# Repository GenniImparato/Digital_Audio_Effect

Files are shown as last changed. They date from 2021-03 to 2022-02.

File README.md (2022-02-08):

 




# Digital_Audio_Effect

## Index

* ### [Overview](#intro)
* ### [Videos](#videos)
* ### [Requirements](#req)
  * #### [Hardware](#hw)
  * #### [Software](#sw)
* ### [Getting Started](#get)
* ### [DSP Effects](#dsp)
  * #### [Delay](#delay)
  * #### [Filter](#filter) 
* ### [Future Improvements](#future)

## Overview
This project is a platform to experiment with **real-time DSP effects** on
audio, with an STM32 microprocessor, using a multi-threaded, real-time environment.
The application has been developed on top of the **Miosix** embedded operative system which provided real-time operating system (RTOS) features, as well as a native multi-threaded enviroment.
A full detailed document explaining the project in details can be found at:
https://github.com/GenniImparato/Digital_Audio_Effect/blob/main/docs/report/Digital_Audio_Effects.pdf

## Videos
https://user-images.githubusercontent.com/37338634/153053574-94ea6515-ac46-4c21-b3ac-aa7877b238f6.mp4

https://user-images.githubusercontent.com/37338634/153054718-db798998-3f35-4ed6-b5b4-32b3baa28a30.mp4

https://user-images.githubusercontent.com/37338634/153054537-bed419cf-c9f3-40c2-ad0e-0b04481bedc5.mp4

## Requirements

### Hardware Requirements
- STM32F407 Discovery Board
- Custom PCB (see `hardware` folder for more details)

### Software Requirements
- [Miosix](https://miosix.org/) OS
- [QSTLink2](https://github.com/fpoussin/QStlink2) for board configuration

## Getting started

1. Connect the microcontroller to the PC with the USB cable or with the external power supply of the PCB.

2. Open `QSTLink2` to connect the board through the `connect` command.

3. Open a terminal, go to the `firmware` folder and type `make` to compile the project.

   ```
   cd path/to/project/firmware   
   make
   ```

4. From `QSTLink2`, send the code to the board through the `send` command.

## DSP Effects
The following are the implemented DSP effects, which values can be dinamically modified. 

### Delay
As the name implies, this effect delays the flow of the audio source by a given amount.

### Filter
This effect can be configured as:
- Low-pass filter
- High-pass filter
- Band-pass filter

Each of those modes can be dinamically changed, as well as their values.

## Future Improvements
**[+]** Implementation of more audio effects

**[+]** Anti-aliasing filtering

**[+]** Sine curves visualization

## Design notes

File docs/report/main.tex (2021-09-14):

%%%%%%%%%%%%%%%%%%%%%%%%%%%%%%%%%%%%%%%%%
% University Assignment Title Page 
% LaTeX Template
% Version 1.0 (27/12/12)
%
% This template has been downloaded from:
% http://www.LaTeXTemplates.com
%
% Original author:
% WikiBooks (http://en.wikibooks.org/wiki/LaTeX/Title_Creation)
%
% License:
% CC BY-NC-SA 3.0 (http://creativecommons.org/licenses/by-nc-sa/3.0/)
% 
% Instructions for using this template:
% This title page is capable of being compiled as is. This is not useful for 
% including it in another document. To do this, you have two options: 
%
% 1) Copy/paste everything between \begin{document} and \end{document} 
% starting at \begin{titlepage} and paste this into another LaTeX file where you 
% want your title page.
% OR
% 2) Remove everything outside the \begin{titlepage} and \end{titlepage} and 
% move this file to the same directory as the LaTeX file you wish to add it to. 
% Then add \input{./title_page_1.tex} to your LaTeX file where you want your
% title page.
%
%%%%%%%%%%%%%%%%%%%%%%%%%%%%%%%%%%%%%%%%%
%\title{Title page with logo}
%----------------------------------------------------------------------------------------
%	PACKAGES AND OTHER DOCUMENT CONFIGURATIONS
%----------------------------------------------------------------------------------------

\documentclass[12pt]{article}
\usepackage[english]{babel}
\usepackage[utf8x]{inputenc}
\usepackage{amsmath}
\usepackage{graphicx}
\usepackage{float}
\usepackage{listings}
\usepackage[colorinlistoftodos]{todonotes}
\usepackage{textcomp}

\usepackage{geometry}
 \geometry{
 a4paper,
 total={170mm,257mm},
 left=20mm,
 top=20mm,
 }
 
 % Better inline directory listings
\usepackage{xcolor}
\definecolor{light-gray}{gray}{0.95}
\newcommand{\code}[1]{\colorbox{light-gray}{\texttt{#1}}}

% Paragraph formatting
\setlength{\parindent}{0em}
\setlength{\parskip}{1em}

% Subsubsubsection
% \usepackage{titlesec}
% \setcounter{secnumdepth}{4}
% \titleformat{\paragraph}
% {\normalfont\normalsize\bfseries}{\theparagraph}{1em}{}
% \titlespacing*{\paragraph}
% {0pt}{3.25ex plus 1ex minus .2ex}{1.5ex plus .2ex}

\usepackage{titlesec}
\usepackage{hyperref}

\titleclass{\subsubsubsection}{straight}[\subsection]

\newcounter{subsubsubsection}[subsubsection]
\renewcommand\thesubsubsubsection{\thesubsubsection.\arabic{subsubsubsection}}
\renewcommand\theparagraph{\thesubsubsubsection.\arabic{paragraph}} % optional; useful if paragraphs are to be numbered

\titleformat{\subsubsubsection}
  {\normalfont\normalsize\bfseries}{\thesubsubsubsection}{1em}{}
\titlespacing*{\subsubsubsection}
{0pt}{3.25ex plus 1ex minus .2ex}{1.5ex plus .2ex}

\makeatletter
\renewcommand\paragraph{\@startsection{paragraph}{5}{\z@}%
  {3.25ex \@plus1ex \@minus.2ex}%
  {-1em}%
  {\normalfont\normalsize\bfseries}}
\renewcommand\subparagraph{\@startsection{subparagraph}{6}{\parindent}%
  {3.25ex \@plus1ex \@minus .2ex}%
  {-1em}%
  {\normalfont\normalsize\bfseries}}
\def\toclevel@subsubsubsection{4}
\def\toclevel@paragraph{5}
\def\toclevel@paragraph{6}
\def\l@subsubsubsection{\@dottedtocline{4}{7em}{4em}}
\def\l@paragraph{\@dottedtocline{5}{10em}{5em}}
\def\l@subparagraph{\@dottedtocline{6}{14em}{6em}}

% Format of references to sections
\AtBeginDocument{%
  \@ifdefinable{\myorg@nameref}{%
    \LetLtxMacro\myorg@nameref\nameref
    \DeclareRobustCommand*{\nameref}[1]{%
      \emph{\myorg@nameref{#1}}%
    }%
  }%
}

\makeatother

\setcounter{secnumdepth}{4}
\setcounter{tocdepth}{4}

\begin{document}
\textwidth=15cm

\lstset{language=C++,
                basicstyle=\fontsize{10}{10}\ttfamily,
                keywordstyle=\color{blue}\ttfamily,
                stringstyle=\color{red}\ttfamily,
                commentstyle=\color{gray!80}\ttfamily,
                morecomment=[l][\color{magenta}]{\#}
}

\begin{titlepage}

\newcommand{\HRule}{\rule{\linewidth}{0.5mm}} % Defines a new command for the horizontal lines, change thickness here

\center % Center everything on the page
 
%----------------------------------------------------------------------------------------
%	HEADING SECTIONS
%----------------------------------------------------------------------------------------

\textsc{\LARGE Politenico di Milano}\\[1.5cm] % Name of your university/college
\textsc{\Large Dipartimento Elettronica, Informazione e Bioingegneria}\\[0.5cm] % Major heading such as course name
\textsc{\large HEAPLab Project Report}\\[0.5cm] % Minor heading such as course title

%----------------------------------------------------------------------------------------
%	TITLE SECTION
%----------------------------------------------------------------------------------------

\HRule \\[0.4cm]
{ \huge \bfseries Digital Audio Effects}\\[0.4cm] % Title of your document
\HRule \\[1.5cm]
 
%----------------------------------------------------------------------------------------
%	AUTHOR SECTION
%----------------------------------------------------------------------------------------

\begin{minipage}{0.4\textwidth}
\begin{flushleft} \large
\emph{Authors:}\\
Generoso \textsc{Imparato} \newline
Yazan \textsc{Matar}
\end{flushleft}
\end{minipage}
~
\begin{minipage}{0.4\textwidth}
\begin{flushright} \large
\emph{Supervisor:} \\
Federico \textsc{Terraneo} % Supervisor's Name
\end{flushright}
\end{minipage}\\[2cm]

% If you don't want a supervisor, uncomment the two lines below and remove the section above
%\Large \emph{Author:}\\
%John \textsc{Smith}\\[3cm] % Your name

%----------------------------------------------------------------------------------------
%	DATE SECTION
%----------------------------------------------------------------------------------------

{\large \today}\\[2cm] % Date, change the \today to a set date if you want to be precise

%----------------------------------------------------------------------------------------
%	LOGO SECTION
%----------------------------------------------------------------------------------------

\\[1cm] % Include a department/university logo - this will require the graphicx package

\emph{Github repo:}\\
\href{https://github.com/GenniImparato/Digital\_Audio\_Effect}{https://github.com/GenniImparato/Digital\_Audio\_Effect}\par
 
%----------------------------------------------------------------------------------------

\vfill % Fill the rest of the page with whitespace

\end{titlepage}

\tableofcontents
\newpage

\section{Introduction}
\label{sec:Intro}

The aim of this project is to create a platform to experiment with real-time DSP effects on audio, with an STM32 microprocessor, using a multi-threaded, real-time environment. \\
We designed an audio chain system with the following specifications:

\begin{itemize}
    \item Input audio can be selected from two sources:
        \begin{itemize}
          \item Audio sampled from an analog audio signal coming from a jack connector
          \item Audio generated by a software audio synthesizer
        \end{itemize}
    \item Audio stream coming from the selected source can be sent through different selectable DSP effects 
    \item Output audio can be heard in real-time with a speaker, as well as earphones through the jack connector
    \item Synthesizer, as well as the effects, has parameters that can be changed in real-time.
\end{itemize}

To realize such functionalities, and to better visualize, hear, and control the system, we designed an auxiliary PCB with extra hardware which will be described in detail in the relative section.

\newpage

\section{Design and Implementation}
\label{sec:Design}
In this section we describe the hardware components and functionalities as well as the software implementation and how those components interact with one another.

\subsection{Hardware}
\label{sec:HW}
In the following sections we analyze in detail the hardware components used for this project, which are the \textbf{STM32F407 Discovery Board} and the \textbf{custom PCB} designed to improve the user experience.

\subsubsection{STM32F407 Discovery Board}
The microcontroller used for the project is the
STM32F407 Discovery Board, which offers (mainly for this project) the following features:

\begin{itemize}
    \item STM32F407VGT6 microcontroller featuring 32-bit Arm\textsuperscript{\textregistered} Cortex\textsuperscript{\textregistered}-M4 with FPU core
    \item 1-Mbyte Flash memory and 192-Kbyte RAM
    \item Audio DAC with integrated class D speaker driver
    \item User and reset push-buttons
    \item Stereo headphone output jack
    \item External application power supply: 3V and 5V
\end{itemize}
For more specifications about the board, read the datasheet and the user manual or go to the manufacturer website.

\subsubsection{Custom PCB}
\label{sec:PCB}
We designed a PCB in Eagle with connectors to insert the STM32F407 discovery board.
The PCB contains extra hardware useful for the project, such as:
\begin{itemize}
    \item Speaker with an amplifier circuit
    \item Audio buffer for ADC sampling
    \item Led matrix [10x15]
    \item Linear potentiometers (for effect controls)
    \item Logarithmic potentiometer (for amplifier volume)
    \item External power supply
\end{itemize}

Details on the PCB are shown in the next sections.

\subsubsubsection{Circuits}
\label{sec:Circuit}

    \begin{figure}[H]
      \centering
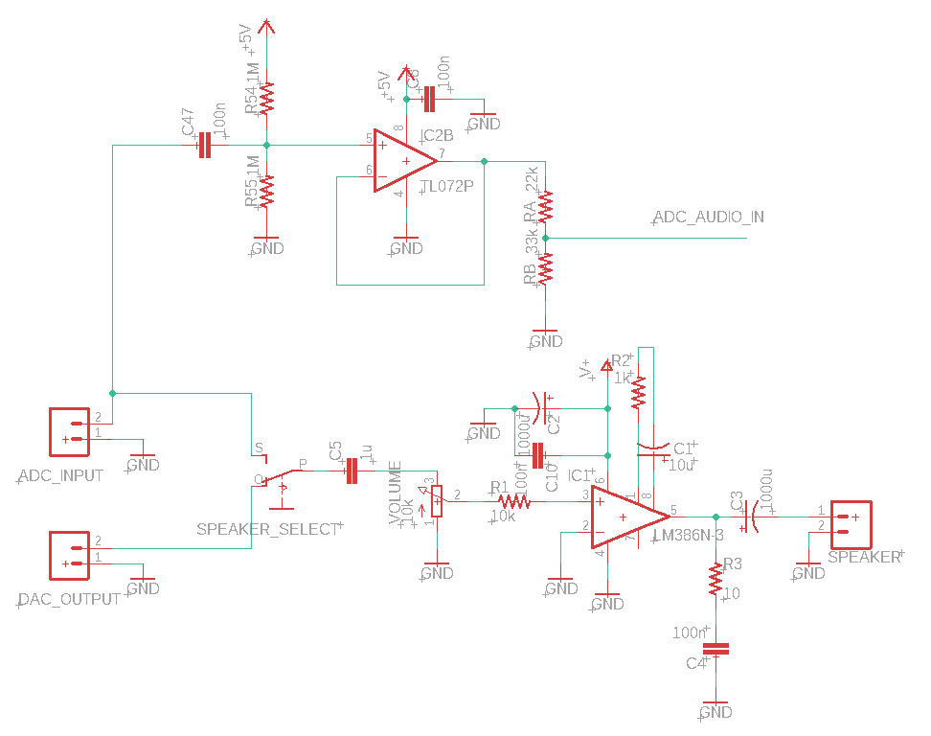
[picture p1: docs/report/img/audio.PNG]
        
        \caption{Audio circuit}
    \end{figure}
    
    This circuit contains a buffer between the input analog audio signal and the STM32 internal ADC input.\\
    The signal is shifted in range from 0 to 3.3V and centered around 1.65 V to be sampled by the ADC.\\
    It also contains the amplifier circuit that drives the 8 ohm speaker on the board, including a volume potentiometer. \\
    The input of the speaker amplifier can be selected with a switch between the raw input audio and the DAC output of the discovery board.
    
    \begin{figure}[H]
      \centering
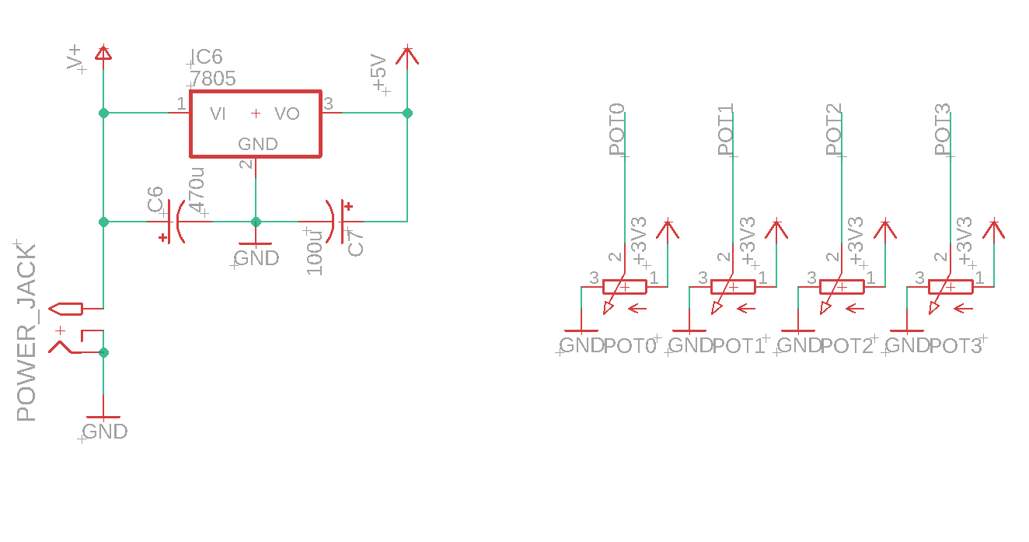
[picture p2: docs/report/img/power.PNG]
        
        \caption{Power and potentiometers circuit}
    \end{figure}
    
    The input voltage from the power is applied directly to the speaker amplifier power supply, while the voltage for the discovery board is obtained by a 5V voltage regulator.
    
    \begin{figure}[H]
      \centering
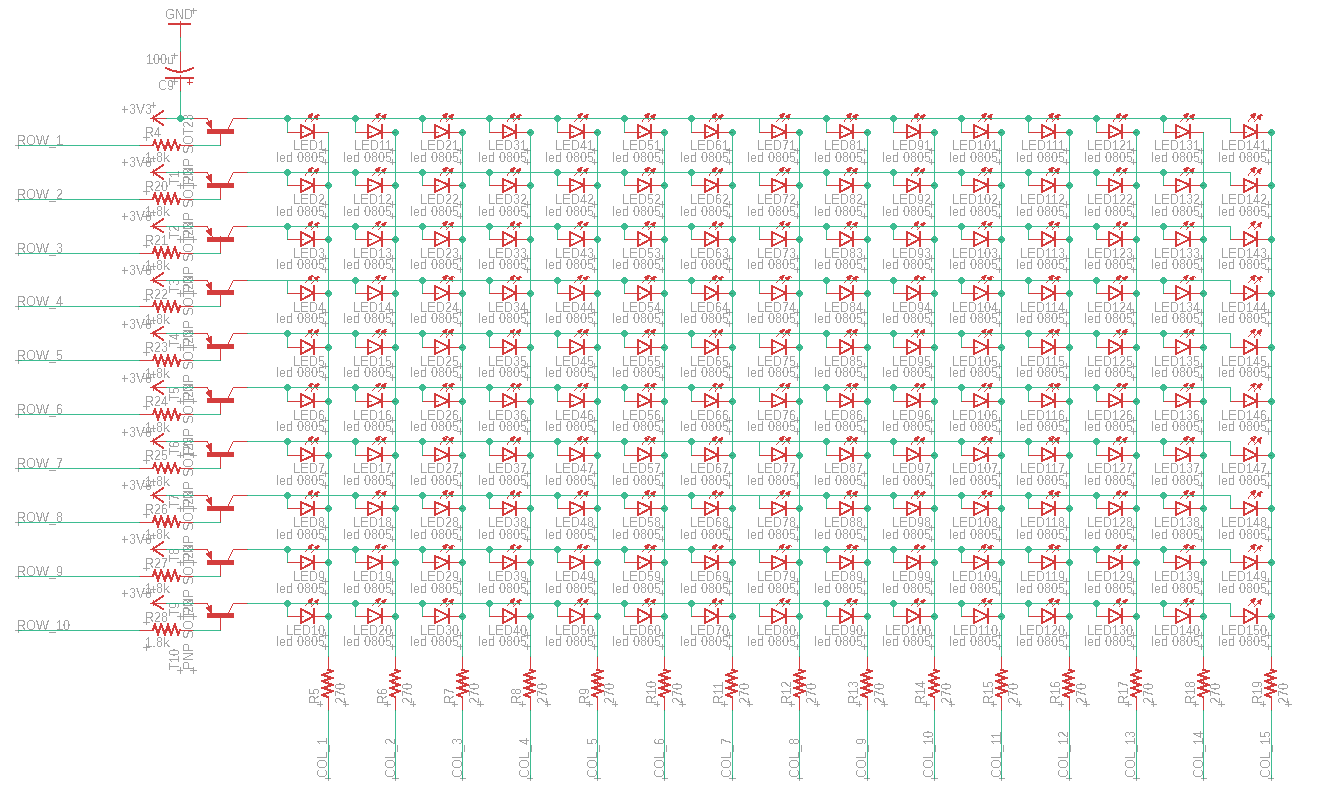
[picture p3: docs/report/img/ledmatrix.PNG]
        
        \caption{Led matrix circuit}
    \end{figure}
    
    The led matrix is made with 150 SMD leds, divided in 10 rows and 15 columns.\\
    Each row is controlled by a PNP transistor with the base connected to a GPIO pin of the discovery board. Columns are connected directly to GPIO pins.
    
    \begin{figure}[H]
      \centering
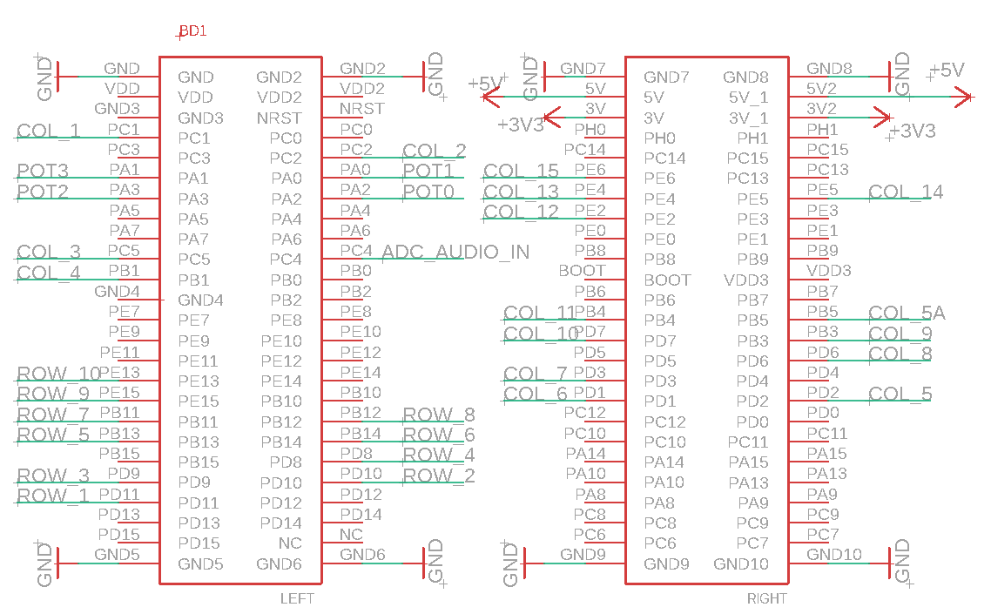
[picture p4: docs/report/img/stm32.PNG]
        
        \caption{STM32F407 Discovery Board connectors}
    \end{figure}
    
    This connectors allow to easily insert and remove the STM32F407 Discovery Board from the PCB.

\newpage
\subsubsubsection{Layout}
\label{sec:Layout}
    
    \begin{figure}[H]
      \centering
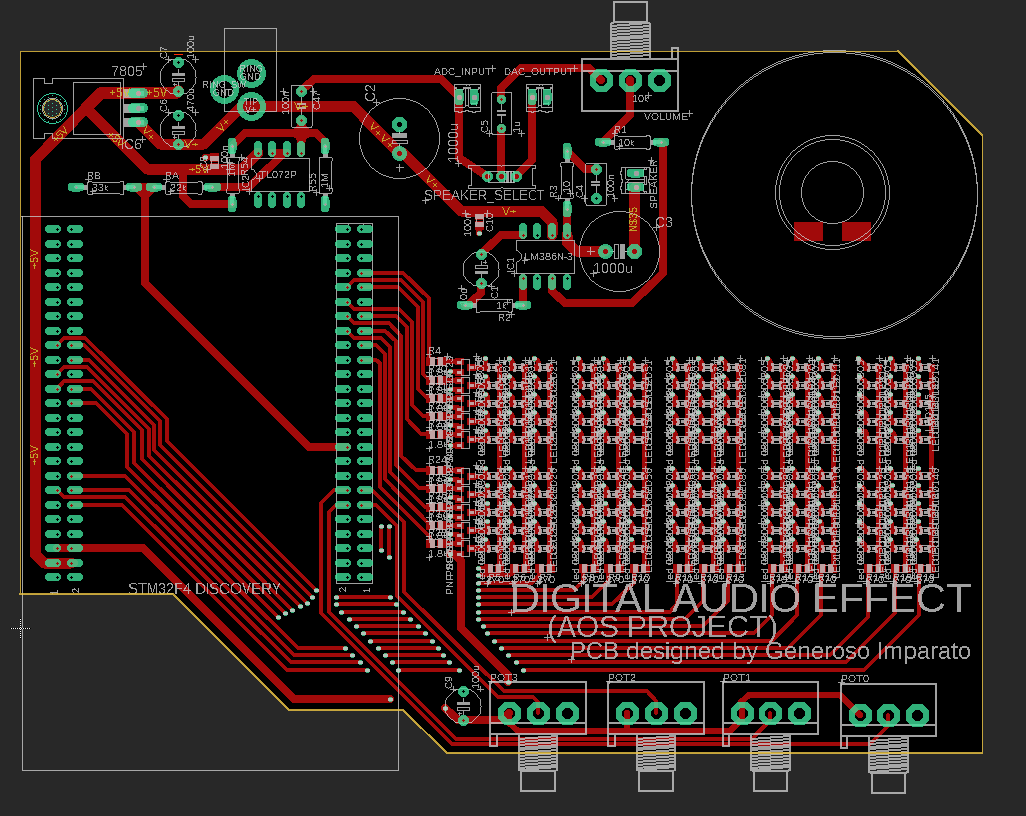
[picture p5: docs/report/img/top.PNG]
        
        \caption{top layer}
    \end{figure}
    
    \begin{figure}[H]
      \centering
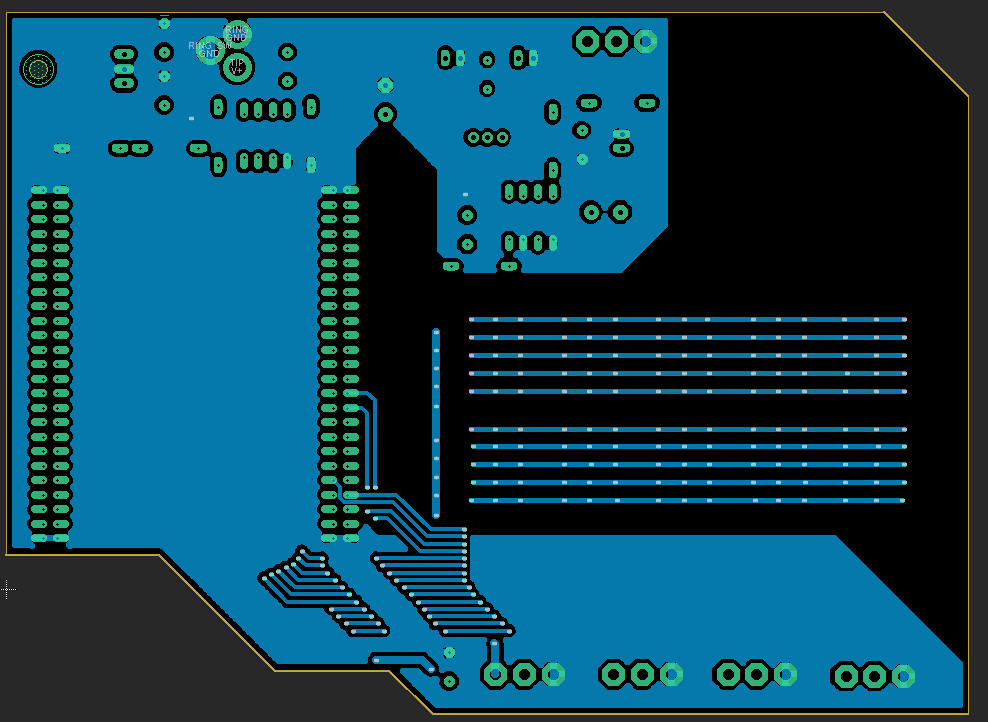
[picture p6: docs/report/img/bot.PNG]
        
        \caption{bottom layer}
    \end{figure}
    
    \newpage
    
    \subsubsubsection{Renderings}
    
    \begin{figure}[H]
      \centering
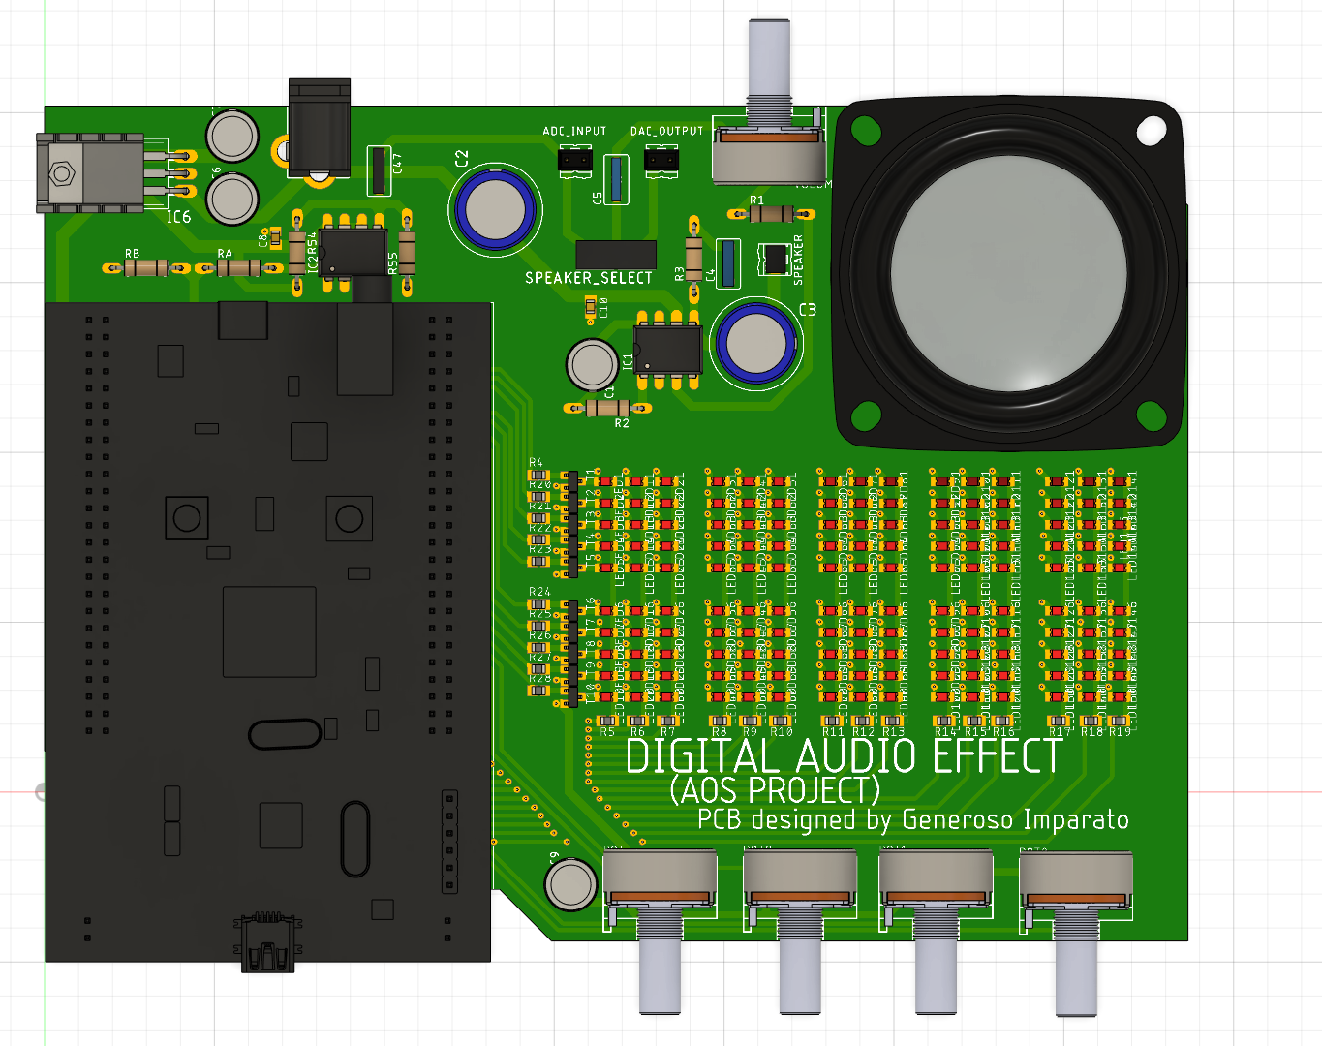
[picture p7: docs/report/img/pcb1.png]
        
    \end{figure}
    
    \begin{figure}[H]
      \centering
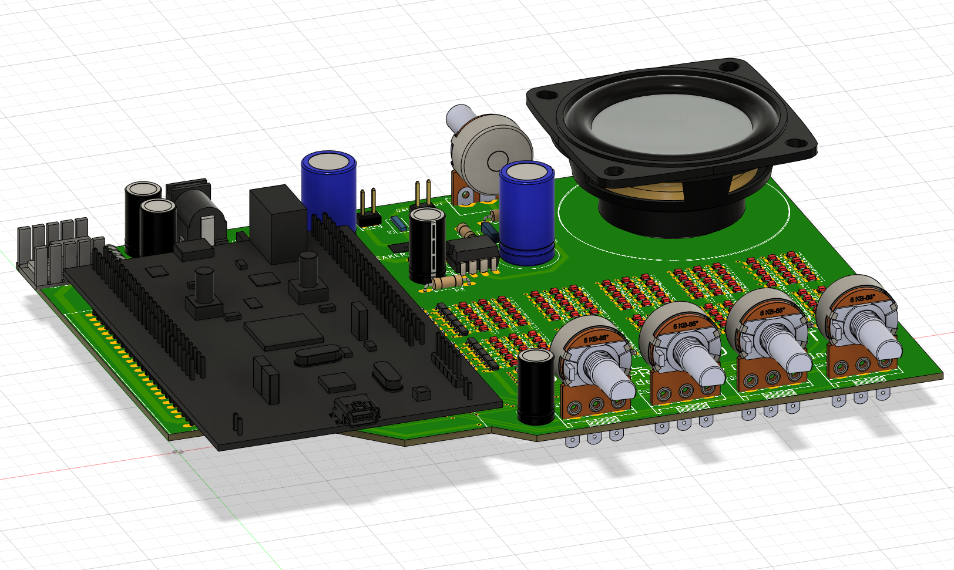
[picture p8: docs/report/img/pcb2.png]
        
    \end{figure}
    
    \vfill

\subsection{Software}
\label{sec:SW}
In this section we describe the real-time OS utilized, the structure of our code in terms of optimizations and scalability, as well as our design choices regarding the management of the various threads and the implementation of different drivers.\\
Finally, we talk about the digital audio effects and their implementation in detail.
    
\subsubsection{Miosix}
\label{sec:Miosix}

Miosix is an embedded OS kernel developed by Federico Terraneo designed to run on 32bit microcontrollers, especially on STM32, EFM32 and LPC2000 microcontroller families. \par

It is used for real-time operating applications and provides operative system abstraction layers such as single process, multi-threading and multi-process (experimental). \par

There is also support for the standard POSIX thread API (threads, mutexes and condition variables) other than full support for C and C++ standard libraries. The Miosix kernel is licensed under the GPL license.

\subsubsubsection{OS Choice}

This project heavily relies on multi-threading and real-time management, so this OS was a good fit, since it supports multi-threading natively, as well as synchronization mechanisms.\par

Another advantage is the small code size, fundamental for limited flash memory as in the case of most microcontrollers.

\subsubsection{Multi-threading Design}
\label{sec:Thread}

\begin{figure}[H]
    \begin{figure}[H]
    \centering
        
        \caption{Diagram Legenda}
    \end{figure}
        
    \centering
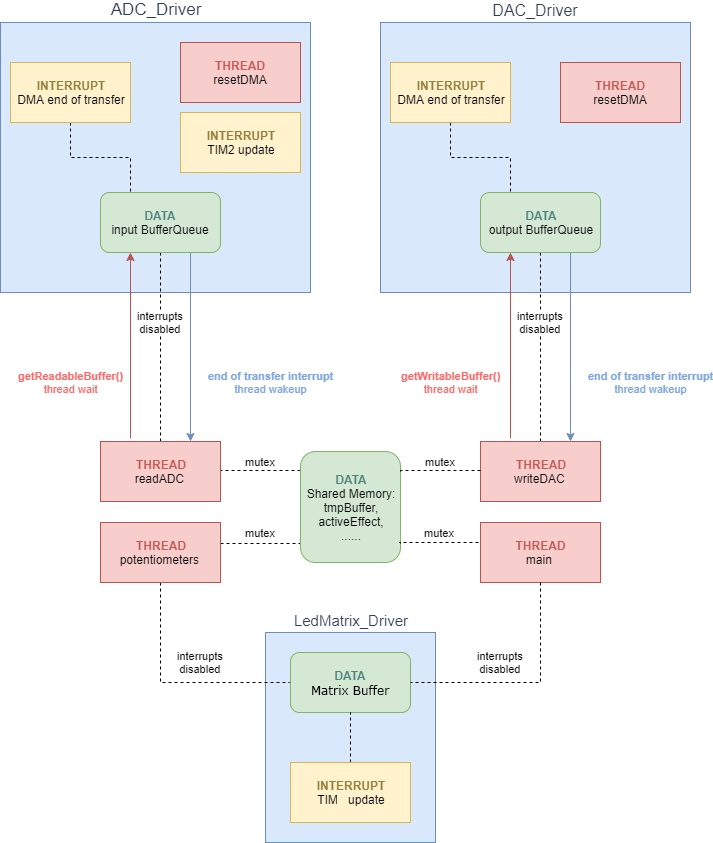
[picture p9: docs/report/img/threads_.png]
        
        \caption{Threads, interrupts and data access relationships}
\end{figure}
        
\newpage

The application is realized with 6 threads.
The two most important threads \code{readADC} and \code{writeDAC} have the highest priority because they should be responsive to allow the audio stream without lags or skipping buffers.\par
\code{readADC} reads from a buffer queue in the \code{ADC\_Driver}, which is filled with audio sampled from ADC at 44,1 kHZ, in a similar way \code{writeDAC} writes in the buffer queue of the \code{DAC\_Driver}.\\
When \code{getReadableBuffer()} is called the \code{readADC} thread is put in a wait state until a buffer is available to be read, when the DMA has finished the transfer.\\
In a similar way, when \code{getWritableBuffer()} is called, the \code{writeDAC} thread is put in wait until a buffer is available to be wrote. \par

In order for the threads to be synchronized, it is required that the samples in input, and the ones in output are read/wrote at the same frequency, which in this case is 44,1 Khz, because it is a standard sampling frequency for audio. \\
The input/output buffer queues are accessed by interrupts (DMA) and threads (\code{readADC}/\code{writeDAC}), so to avoid concurrency problems, interrupts are disabled when accessing from the thread.\par

The potentiometer and main thread spin at fixed rates and are responsible for reading potentiometers values from the ADC and for checking the button to switch effect/audio source.\par

The two \code{resetDMA} threads are responsible to restart the DMAs in case the process stops because no buffer was available to be read/wrote.

% \newpage
    
\subsubsection{Drivers}
\label{sec:Drivers}
In order to hide the low level handling of peripheral registers and the logic required, we wrote some classes that act as drivers, providing higher level methods to use the ADC, DAC and Led Matrix.
The drivers are implemented as static classes.

\subsubsubsection{TIMx Configuration}
\label{sec:TIMx}

Since drivers use hardware timer interrupts, we will show how the right frequency of the interrupts is obtained. \par

Starting from the internal clock frequency ($168 MHz$), we pass through the AHB Prescaler and the AHB1 Prescaler, so the initial timer frequency is:

$$f_{TIMx} = \frac{f_{clk,int}}{AHB\_PSC \cdot APB1\_PSC} = \frac{168MHz}{4} =  42Mhz$$

Then, the frequency can be further prescaled setting the 16 bit prescaler (TIMx\_PSC) and the auto-reload register (TIMx\_ARR), according to this formula:

$$f_{event} = \frac{f_{TIMx}}{(TIMx\_PSC+1)\cdot(TIMx\_ARR+1)}$$

\subsubsubsection{ADC Driver}
\label{sec:ADC}
The peripherals used by the driver are ADC1, ADC2, TIM2, DMA2.\par
ADC2 is configured in DMA mode, single conversion triggered from the TIM2 update event and the channel is connected to the audio buffer input circuit.\par

TIM2's update frequency is set according to this formula, which was explained in the \nameref{sec:TIMx} section:

$$f_{update} = \frac{f_{TIM2}}{(TIM2\_PSC+1)\cdot(TIM2\_ARR+1)} = \frac{42MHz}{(16+1)\cdot(55+1)} = 44.1kHz$$

DMA2 is set in peripherals to memory mode to fill \code{AUDIO\_BUFFERS\_SIZE} number of samples of the input buffer queue.\par
    
The ADC resolution is 12 bits, so the values of the samples are in range from $0$ to $2^{12}-1 = 4095$
    
The driver acts like a \textit{producer} of audio buffers in the input queue.
If the queue is full and a new buffer cannot be added, the DMA stops, so there is a thread that spins in the background to restart the DMA as soon as the queue is free again.

\code{ADC\_Driver} provides access to the reader thread through the following method: \\
\begin{lstlisting}
const unsigned short* ADC_Driver::getReadableBuffer(miosix::Thread* readerThread) 
\end{lstlisting}
The reader thread is set in wait state if a buffer is not available to be read, it will be woken up later, when the DMA end of transfer interrupt occurs and the buffer is filled again.\par
    
The driver has also methods to perform single ADC conversions or multiple conversions with a low pass filter.
For these functionalities ADC1 is used:\\
\begin{lstlisting}
unsigned short ADC_Driver::singleConversion(unsigned short channel);
unsigned short ADC_Driver::filterConversions(unsigned short channel);
\end{lstlisting}
    
\subsubsubsection{DAC Driver}
\label{sec:DAC}
The DAC used is the CS43L22, which is already mounted on the discovery board.\\
It operates in I2S mode, for which the SPI3 peripheral is used with the internal audio PLL set to 44,1 kHz.\\
DMA1 is set in memory to peripheral mode to send \code{AUDIO\_BUFFERS\_SIZE} number of samples from the the output buffer queue to the DAC through I2S.\\  
I2S protocol uses 16 bit unsigned PCM samples, so the values are in range from $0$ to $2^{16}-1 = 65535$\par

The driver acts like a \textit{consumer} of audio buffers in the output queue.
If there is no buffer available in the queue, the DMA stops, so there is a thread that spins in the background to restart it as soon as the queue is filled again.
    
\code{DAC\_Driver} provides access to the writer thread through the following method: \\
\begin{lstlisting}
unsigned short * DAC_Driver::getWritableBuffer(miosix::Thread* writerThread)
\end{lstlisting}
The writer thread is set in wait state if a buffer is not available to be wrote, it will be woken up later, when the DMA end of transfer interrupt occurs and the queue is free again.\par
    
The DAC output is connected to audio jack on the discovery board, which is then connected to the speaker amplifier on the main PCB with a jack cable.

\subsubsubsection{Led Matrix Driver}
\label{sec:LED}
The Led Matrix serves as the output viewer of this project.
To better handle this component, \code{Led\_Matrix\_Driver} was implemented. \par

\code{Led\_Matrix\_Driver} provides access to the writer thread through the following method: \\
\begin{lstlisting}
void LedMatrix_Driver::setString(const std::string &str);
\end{lstlisting}

This method writes the led values in a buffer according to the string given as input. \\
To write in the buffer, a \code{FastInterruptDisableLock} is needed to avoid concurrency problems with respect to the other threads which access this method. \par
Then, the method \\

\begin{lstlisting}
void LedMatrix_Driver::writeLeds();
\end{lstlisting}
lights up the leds based on the buffer's values, \textit{one row at a time}.

As we can see in the \nameref{sec:Circuit} section of the PCB, there are PNP transistors only for the rows, so we can light up at most one entire row to avoid damaging the board, since the maximum current output allowed by the board is $100 mA$. \\
Running this on a separate thread was not a good choice, since the other threads affected its behaviour in a visible manner, so we chose to implement an \textit{Interrupt Routine} to achieve a constant refresh rate of the led matrix.\\
So we used an internal timer (TIM5) to trigger the IRQ.
First of all, we configured TIM5's frequency according to this formula, which was explained in the \nameref{sec:TIMx} section:

$$f_{update} = \frac{f_{TIM5}}{(TIM5\_PSC+1)\cdot(TIM5\_ARR+1)} = \frac{42MHz}{(349+1)\cdot(239+1)} = 500Hz$$

This means that each row of leds is refreshed in such a way that we can see all of the rows active at the same time.\\
Note that, since an Interrupt call refreshes a single row of the led matrix, lowering the frequency value makes the view unstable.\par

\subsubsection{Audio Chain}
The audio chain is mainly implemented in the \code{readADC}/\code{writeDAC} threads.\\
\code{readADC} thread copies buffers from the \code{ADC\_Driver} into a shared buffer, which is accessed with mutex protection because it is also used by \code{writeDAC} thread.\\ It also converts values from unsigned 12 bit to floating point.\\
\code{writeDAC} is the thread that performs the actual DSP on the buffer, before writing it to the \code{DAC\_Driver}.\par

If the audio source is set to \code{ADC}, the shared buffer is used as input for the active effect DSP algorithm.\\
If the audio source is set to \code{Synthesizer} the shared buffer is not used, because input samples are generated by the thread and then fed into the active DSP algorithm.\\
Then samples are converted from floating point to unsigned 16 bit PCM and sent to the \code{DAC\_Driver}.\\
The number of samples in each buffer can be changed by defining \code{AUDIO\_BUFFERS\_SIZE}, which is currently set to 512.

\subsubsection{DSP Effects}

The synth and the DSP effects are all implemented by extending a base class \code{AudioEffect}, that provides virtual methods that can be overridden to create different effects.\\ 
In particular the DSP algorithm is executed in the method:\\
\begin{lstlisting}
virtual void AudioEffect::writeNextBuffer(float* inBuff, float* outBuff);
\end{lstlisting}
The default implementation just copies \code{inBuff} into \code{outBuff}, applying no effect.\par

This design allows to easily implement different effects, focusing only on the DSP part and avoiding to handle all the audio chain, as well as the controls updating from the potentiometers.\par

The effects included in this demonstration are a \textit{Delay}, a \textit{Filter} and a \textit{Tremolo}.

\subsubsubsection{Delay}
The delay effect is obtained thanks to a circular buffer, which is continuously refilled from the beginning once is full.\\
This buffer has a size that is a multiple of \code{AUDIO\_BUFFERS\_SIZE}, and it is used to keep in memory samples from past buffers.\\
When producing the next buffer, samples from the delay buffer are added to the input, multiplied by a feedback parameter.\\
The maximum delay time depends on the size of the circular buffer, and can be computed as:
$$T_{max} = \frac{buffer\_size}{f_{sampling}}$$
In this case, the circular buffer size is set to:
$$T_{max} = \frac{k\cdot\code{AUDIO\_BUFFERS\_SIZE}}{44.1  kHz} = \frac{45\cdot512}{44.1  kHz} = 522 ms$$

The actual delay time, as well as the feedback are left as parameters controllable with potentiometers.

\subsubsubsection{Filter}
The filter effect implements a simple low-pass, band-pass and high pass filter.\\
Controllable parameters are cutoff frequency and resonance. \\
The DSP algorithm implemented is from Paul Kellett and can be found at:  \\
https://www.musicdsp.org/en/latest/Filters/29-resonant-filter.html

\subsubsubsection{Tremolo}
The tremolo effect applies a modulation on the signal amplitude, which is controlled by a software LFO (low frequency oscillator).\\
The signal samples are multiplied by a factor which is generated by the LFO and the speed can be controlled as parameter.

\subsubsubsection{Synthesizer}
We added a wavetable synthesizer to be used as an audio source.\\
it is implemented by extending the \code{AudioEffect} class in a way similar to the DSP effects, but since it generates the samples from scratch it does not read from \code{inBuffer}, but writes to \code{outBuffer}.\par

Wavetables are pre-computed to make the real-time computations faster, so when the samples are generated, values from the wavetables are used, with proper stretching according to the desired sound frequency.\par

The synthesizer has 3 independent oscillators, each one using a different wavetable: 
\begin{itemize}
    \item Sine
    \item Triangle
    \item Square Wave
\end{itemize}

Those waveforms are added together and multiplied by the respective amplitude, in order to generate the output samples. \\
Each individual oscillator and its parameters can be controlled with potentiometers.

\newpage

Controllable parameters are:
\begin{itemize}
    \item Frequency
    \item Amplitude
    \item Speed
    \item Mode
\end{itemize}

\textit{Speed} parameter controls the speed at which the selected pattern is played.\\
\textit{Mode} allows to select a pattern for the oscillator, such as continuous note, scale, random notes, octaves and so on. \\

\section{Conclusions}
This project covered the development of a system in which multiple audio sources could go through different digital audio effects, all in a real-time environment and with an enhanced user experience brought by a custom PCB.\par

We experienced some noise in the audio sampled from ADC, and we couldn't remove it completely, but overall, we can say that our initial goal was reached and we built a solid base for future improvements.\par

The \code{AudioEffect} class is very easy to extend, so adding a new digital audio effect and viewing it in the led matrix, is a very simple task, and this applies also to adding other audio sources.

\subsection{Future Improvements}

We could implement audio effects which require the usage of a FFT to expand the pool of options.\par
Another possible improvement would be adding an anti-aliasing filter on the audio signal before the ADC sampling, which could maybe solve the noise problem mentioned before.\par
Also, we could use a cleaner power supply and a better analog/digital power separation on the PCB.\par
Finally, an improvement to the user experience would be a better handling of controls shown in the led matrix.

\end{document}

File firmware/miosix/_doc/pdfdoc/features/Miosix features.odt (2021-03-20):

# Miosix kernel 2.0 features

Note: this document is a draft, since the current Miosix version is 1.54. When all planned features will be included, the kernel version will be bumped to 2.0. However, all features described here are already implemented and tested.

### Multiplatform kernel

Miosix is currently available for the ARM7 based LPC2000 family of microcontrollers, and for the ARM Cortex M3 based STM32 microcontrollers.

For each platform it provides:

- A suitable linker script, startup code and low-level routines to allow preemption and context switching.
- A driver to access a serial port.
- A driver to allow the filesystem module read/write access on an SD or MicroSD card.
- A platform independent abstraction over GPIOs, the Gpio tempate class.
- A platform independent set of delay routines, to obtain delays down to microseconds.

In addition, Miosix has been refactored for easy porting to other architectures, by separating architecture independent code from low level code.

### Multithreading support

The Miosix kernel is a single process, multithread kernel. This is because most microcontrollers lack an MMU and therefore are incapable of the memory separation required to fully implement processes.

While multithreading is a key feature of the kernel, available since its first releases, starting from Miosix 1.54 a preliminary implementation of the POSIX thread API is available, with support for threads, mutexes and condition variables.

This is an example of a pthread program (a classic producer-consumer model) that can be run on Miosix. Please note that the same program can be run on a desktop operating systems unchanged:

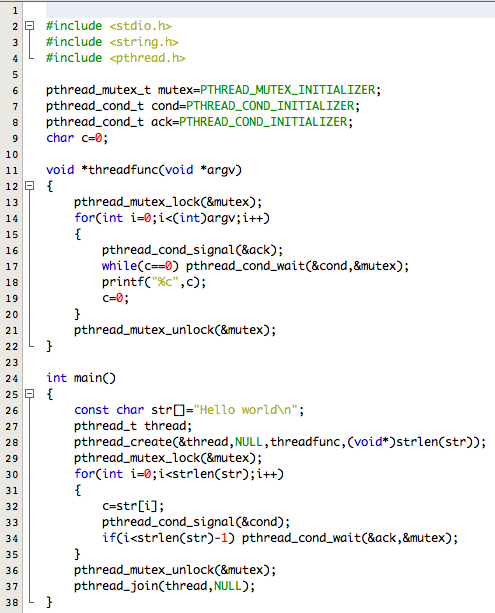
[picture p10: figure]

While this is the same program coded with the native Miosix API:

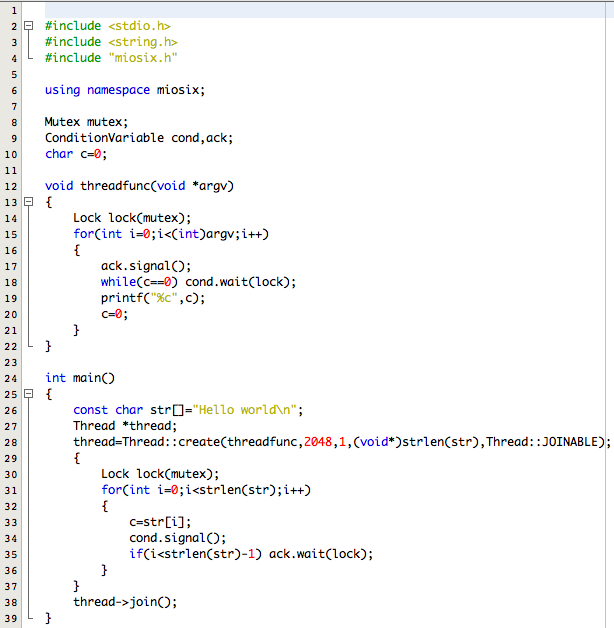
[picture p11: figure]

### C and C++ standard library

Miosix integrates with the Newlib C standard library, which is designed for embedded systems, and with libstdc++, which is the C++ standard library provided with GCC.

The C/C++ library's console I/O facilities (printf, cout) are by default redirected to a serial port, and the filesystem functions (fopen, fstream) are integrated with the filesystem module. The C++'s STL library and exception handling are provided. Dynamic memory allocation is of course available.

This is a simple example that shows C++'s STL and exception support in Miosix. This code would compile without modifications even on a desktop computer:

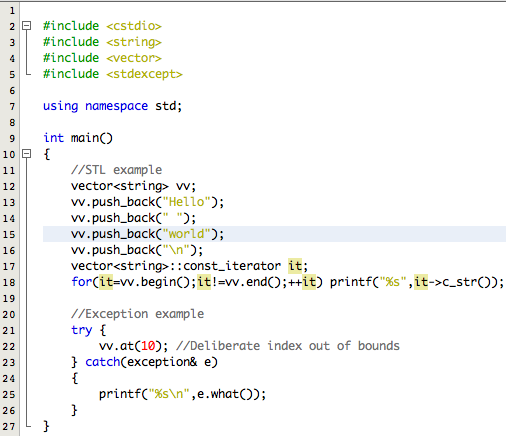
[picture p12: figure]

### Filesystem support

Miosix includes read/write support on FAT16 and FAT32 filesystems. Code to create directories and list their content is also provided.

For write support, the option SYNC_AFTER_WRITE allows to choose the fastest write speed, or a safe mode where data is written to disk as soon as possible, to minimize the risk of data loss in case when power is removed unexpectedly.

Filesystem access is integrated with the C/C++ standard library, so that it is not necessary to learn a custom API to write or read files.

This example shows file read/write using the C library on Miosix. Again, this code would compile without modifications even on a desktop computer:

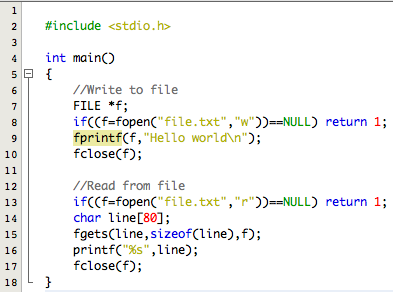
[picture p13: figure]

### Modular architecture

Miosix provides many high level features, but recognizes that the code size associated with them might not be acceptable in all embedded applications.

First of all, part of the code size optimization can be done automatically by the linker. Since Miosix lacks a loader to dynamically load executable code, the list of functions and classes that are used by an application are known at compile time. This means that the linker can strip the parts of the C and C++ libraries that are not used.

In addition, Miosix has modular architecture where the developer can choose only the features required:

- If code does not use C++ exceptions, it is possible to save code size by disabling its support.
- Certain parts of the kernel, such as the filesystem module, can be removed if not used.
- Boot logs and error logs can be removed in release builds.

Lastly it is possible to choose compiler optimization, in miosix/config/Makefile.inc. The default is -O2 (moderate speed optimization), but -Os is available to optimize for minimum size.

As a proof of concept, Miosix 1.54 for stm32 was compiled with the following minimal configuration:

- No C++ exception support (but the rest of the C++ language fatures still available)
- Release mode (code running from FLASH, no JTAG_DISABLE_SLEEP)
- GCC Compiler optimization -Os
- No filesystem
- Options: EXIT_ON_HEAP_FULL, WITH_STDIN_BUFFER, No boot logs, No error logs

The resulting code size was just 6228 Bytes.

However, it is suggested to use a microcontroller with at least 64KB of FLASH and 16KB of RAM.

### Memory statistics gathering

Microcontrollers often have little RAM memory available, and this limitation is even more evident when using multithreading. Since each thread needs to have its own stack, it is important to select the right size for it, not too large to avoid excessie RAM usage, and not too low to cause stack overflows.

Miosix includes code designed to gather statistics about memory about both stack and heap memory usage. These statistics can be used to take decisions at runtime, or simply printed during the development phase, and used as a guide for optimizing code.

The statistics code is in miosix/util.h and is contained in the MemoryProfiling class. To check what this class provides, see the doxygen documentation.

Here is a simple example code:

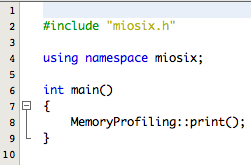
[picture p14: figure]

And the output on the console:

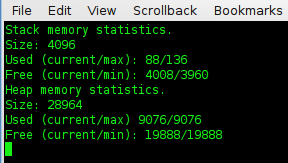
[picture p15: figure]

The print() member fuction of the MemoryProfiling class is designed to print a short summary of the information that can be gathered through this class:

- It prints the stack size of the thread from which it was called. As can be seen, main() has a 4KBytes stack.
- The currently used stack, which is 88Bytes and the maximum stack used since the thread was spawned, 136Bytes.
- The current and minimum free stack, which is simply the stack size minus the used stack.
- The heap size.
- The current and maximum used heap.
- The current and minimum free heap.

While the heap is global in Miosix, which means that all threads share the same heap, each thread has its own stack. This implies that calling MemoryProfiling::print() from different threads will return different data about stack sizes and usage, to reflect the situation of the threads, but the same heap data.

When spawning threads, their stack sized can of course be customized. To see how, look at the doxygen documentation of Thread::create().

The size of the main() thread can be customized too, even if it defaults to 4KB.

### Detailed debug information

When coding is not uncommon to introduce bugs. Miosix can make use of the undelying hardware to catch bugs as soon as possible and make this debug data available to the developer to speed up bug fixing.

As usual the modular architecture of the kernel allows to remove this debug support inside the kernel to minimize code size of release builds. The option is named WITH_ERRLOG and is in miosix/config/miosix_settings.h

This is an example of a pointer error to see how does Miosix react to it.

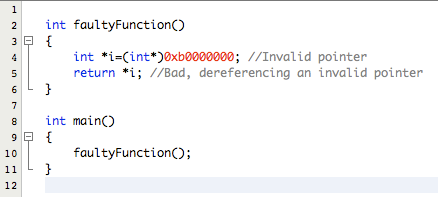
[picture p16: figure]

The location 0xb0000000 in the STM32 microcontroller is an invalid address, so dereferencing the pointer is an error.

This is what Miosix prints on the serial port when this code is run.

The Cortex M3 microcontroller catches the violation and issues a BusFault exception. Miosix kicks in and makes the debug information available. Debug information starts with three asterisks to distinguish it from data that the developer prints through printf.

The debug data gives many precious informations:

- It tells the kind of fault that occurred (BusFault)
- It tells the address of the instruction that caused the fault (0x6800246a). By itself the address might not seem very useful, but using two programs provided with GCC, addr2line and c++filt it is possible to make use of it
  arm-eabi-addr2line 0x6800246a -e main.elf -f | arm-eabi-c++filt
  faultyFunction()
  demo.cpp:5
  As can be seen it is possible to get the name of the function, the file and the source code line (5) where the fault happened. For this information to be reliable, code needs to be compiled with optimizations disabled (using -O0 as OPT_OPTIMIZATION) since optimizations in the compiler, such as function inlining can confuse this.
- It tells the memory location whose attempted access caused the fault (0xb0000000).

Miosix can detect stack overflows using two different checks that are done at every context switch:

- Check that the stack pointer of the preempted thread is within bounds.
- Check that a watermark area placed at the end of each stack has not been overwritten. The size of this area is configurable to optimize the tradeoff between safety and fast context switches. The option is called WATERMARK_LEN.

Of course these are not the only errors that can be detected, other include deadlock caused by a thread locking a non recursive mutex twice, errors in parameters to system calls, attempted use of filesystem calls in builds where the filesystem is not enabled, etc.

The kernel is also friendly towards JTAG in-circuit debuggers, providing an option named JTAG_DISABLE_SLEEP to prevent the idle thread from putting the processor in low power mode, since this confuses in-circuit debuggers.

### Suitable for low power applications

Most modern microcontrollers provide an idle mode where the CPU is stopped waiting for interrupts while peripherals are running, which can provide a consderable power consumption reduction.

Miosix takes advantage of this, in a way that is transparent to the developer. Its kernel, when no thread is ready to run, runs the idle thread which puts the CPU in idle mode.

This simple exampe code blinks a led at an 1Hz rate.

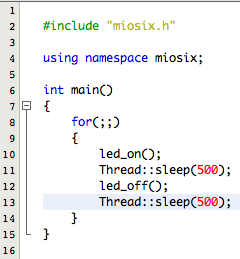
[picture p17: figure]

In this application the CPU is idle for most of the time, because when main() calls sleep(), no thread is ready to run, and the idle thread puts the CPU in idle state.

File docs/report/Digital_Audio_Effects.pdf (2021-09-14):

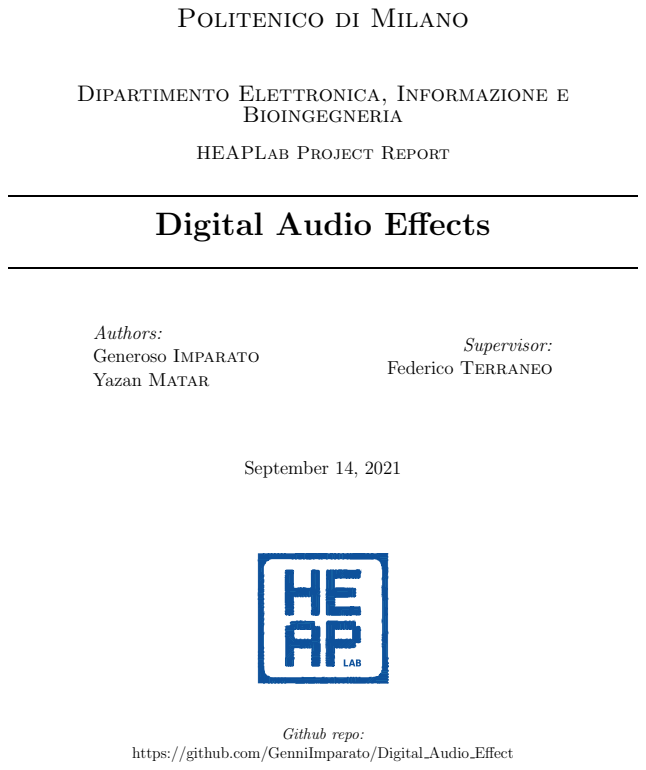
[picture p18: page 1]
Bioingegneria; Authors: Generoso Imparato Yazan Matar; Supervisor: Federico Terraneo; September 14, 2021; Github repo:

Politenico di Milano

Dipartimento Elettronica, Informazione e

HEAPLab Project Report

Digital Audio Effects

https://github.com/GenniImparato/Digital Audio Effect

## Contents

1 Introduction | 2
2 Design and Implementation | 3
3 Conclusions | 16

## 1 Introduction

The aim of this project is to create a platform to experiment with real-time DSP effects on audio, with an STM32 microprocessor, using a multi-threaded, real-time environment.
We designed an audio chain system with the following specifications:
- Input audio can be selected from two sources:

– Audio sampled from an analog audio signal coming from a jack connector

– Audio generated by a software audio synthesizer

- Audio stream coming from the selected source can be sent through different selectable DSP effects
- Output audio can be heard in real-time with a speaker, as well as earphones through the jack connector
- Synthesizer, as well as the effects, has parameters that can be changed in real-time.

To realize such functionalities, and to better visualize, hear, and control the system, we designed an auxiliary PCB with extra hardware which will be described in detail in the relative section.

## 2 Design and Implementation

In this section we describe the hardware components and functionalities as well as the software implementation and how those components interact with one another.

### 2.1 Hardware

In the following sections we analyze in detail the hardware components used for this project, which are the STM32F407 Discovery Board and the custom PCB designed to improve the user experience.

### 2.1.1 STM32F407 Discovery Board

The microcontroller used for the project is the STM32F407 Discovery Board, which offers (mainly for this project) the following features:

- STM32F407VGT6 microcontroller featuring 32-bit Arm® Cortex®-M4 with FPU core
- 1-Mbyte Flash memory and 192-Kbyte RAM
- Audio DAC with integrated class D speaker driver
- User and reset push-buttons
- Stereo headphone output jack
- External application power supply: 3V and 5V

For more specifications about the board, read the datasheet and the user manual or go to the manufacturer website.

### 2.1.2 Custom PCB

We designed a PCB in Eagle with connectors to insert the STM32F407 discovery board. The PCB contains extra hardware useful for the project, such as:

- Speaker with an amplifier circuit
- Audio buffer for ADC sampling
- Led matrix [10x15]
- Linear potentiometers (for effect controls)
- Logarithmic potentiometer (for amplifier volume)
- External power supply

Details on the PCB are shown in the next sections.

### 2.1.2.1 Circuits


Figure 1: Audio circuit

This circuit contains a buffer between the input analog audio signal and the STM32 internal ADC input.
The signal is shifted in range from 0 to 3.3V and centered around 1.65 V to be sampled by the ADC.
It also contains the amplifier circuit that drives the 8 ohm speaker on the board, including a volume potentiometer.
The input of the speaker amplifier can be selected with a switch between the raw input audio and the DAC output of the discovery board.

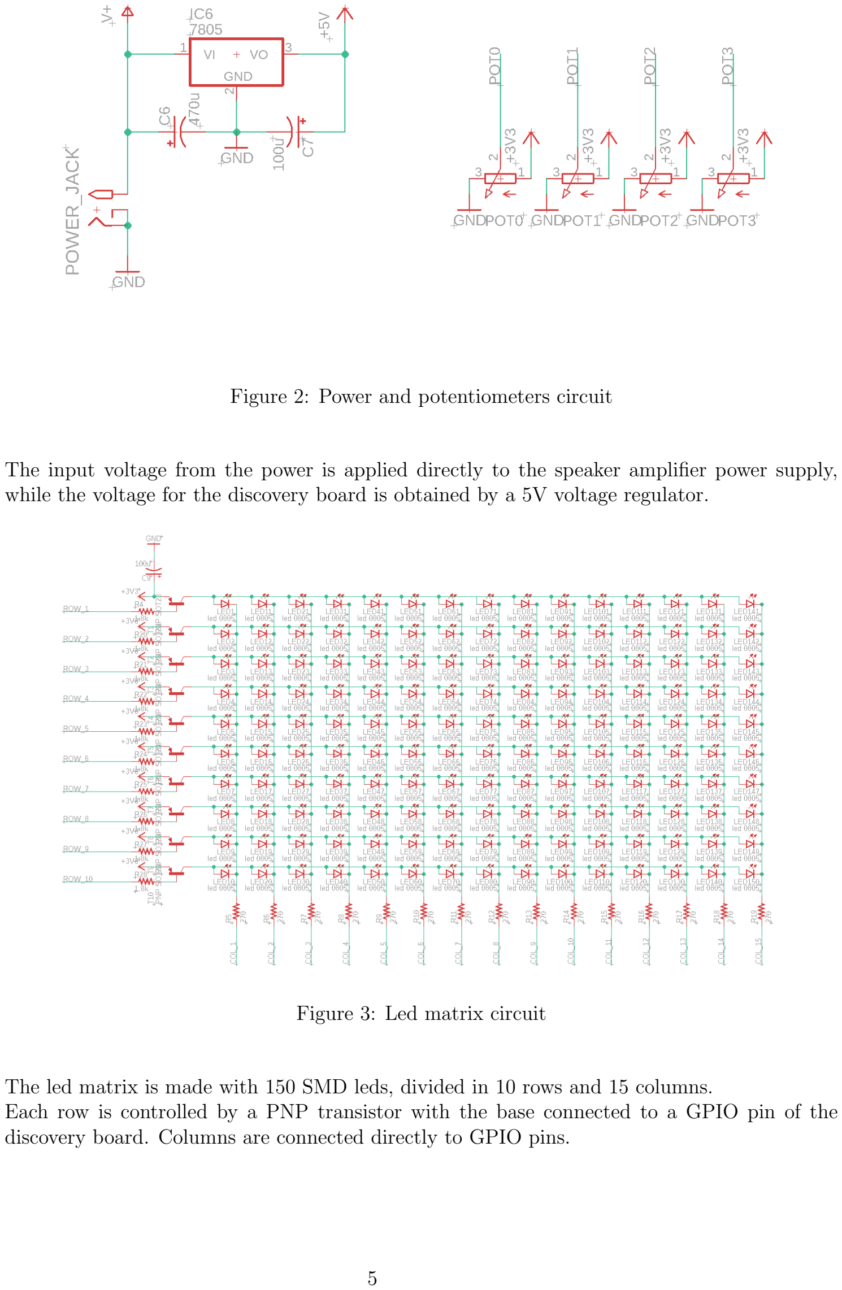
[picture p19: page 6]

Figure 2: Power and potentiometers circuit

The input voltage from the power is applied directly to the speaker amplifier power supply, while the voltage for the discovery board is obtained by a 5V voltage regulator.

Figure 3: Led matrix circuit

The led matrix is made with 150 SMD leds, divided in 10 rows and 15 columns.
Each row is controlled by a PNP transistor with the base connected to a GPIO pin of the discovery board. Columns are connected directly to GPIO pins.


Figure 4: STM32F407 Discovery Board connectors

This connectors allow to easily insert and remove the STM32F407 Discovery Board from the PCB.

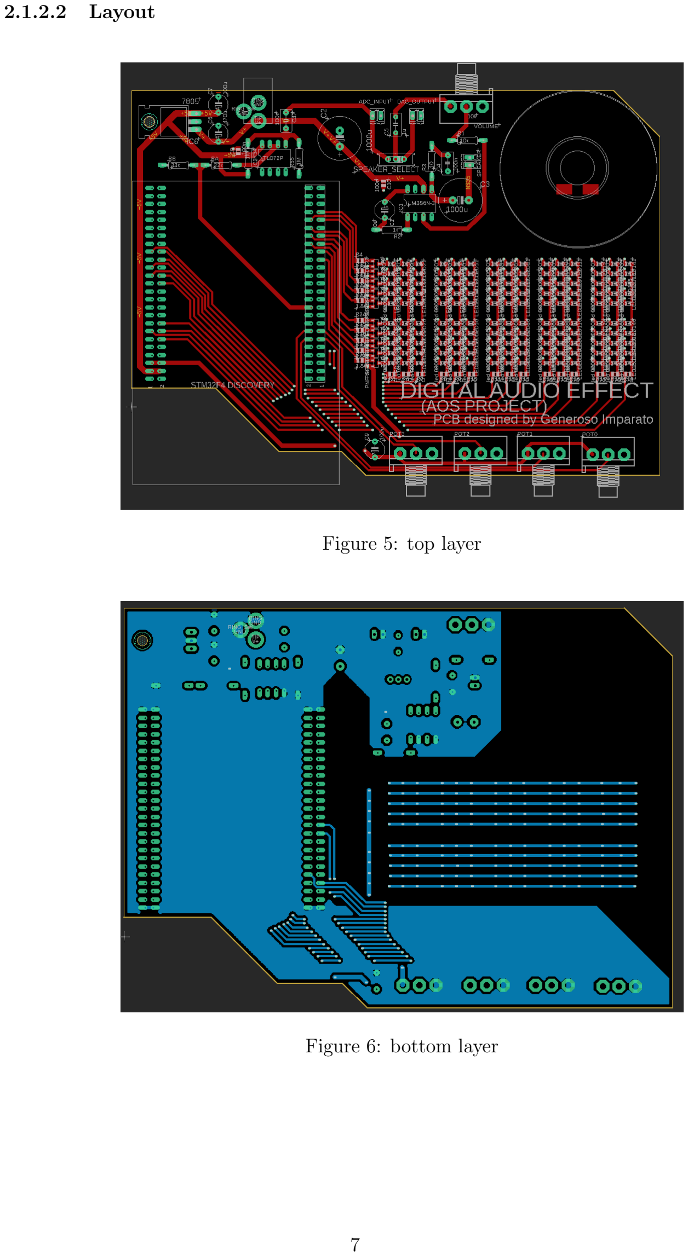
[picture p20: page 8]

### 2.1.2.2 Layout

Figure 5: top layer

Figure 6: bottom layer

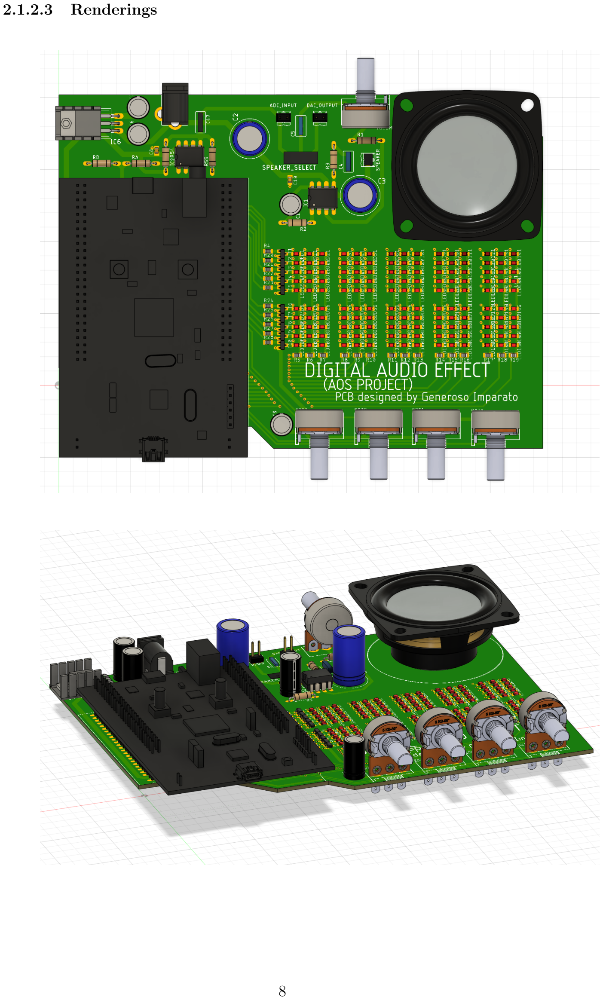
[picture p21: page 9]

### 2.1.2.3 Renderings

### 2.2 Software

In this section we describe the real-time OS utilized, the structure of our code in terms of optimizations and scalability, as well as our design choices regarding the management of the various threads and the implementation of different drivers.
Finally, we talk about the digital audio effects and their implementation in detail.

### 2.2.1 Miosix

Miosix is an embedded OS kernel developed by Federico Terraneo designed to run on 32bit microcontrollers, especially on STM32, EFM32 and LPC2000 microcontroller families.

It is used for real-time operating applications and provides operative system abstraction layers such as single process, multi-threading and multi-process (experimental).

There is also support for the standard POSIX thread API (threads, mutexes and condition variables) other than full support for C and C++ standard libraries. The Miosix kernel is licensed under the GPL license.

### 2.2.1.1 OS Choice

This project heavily relies on multi-threading and real-time management, so this OS was a good fit, since it supports multi-threading natively, as well as synchronization mechanisms.

Another advantage is the small code size, fundamental for limited flash memory as in the case of most microcontrollers.

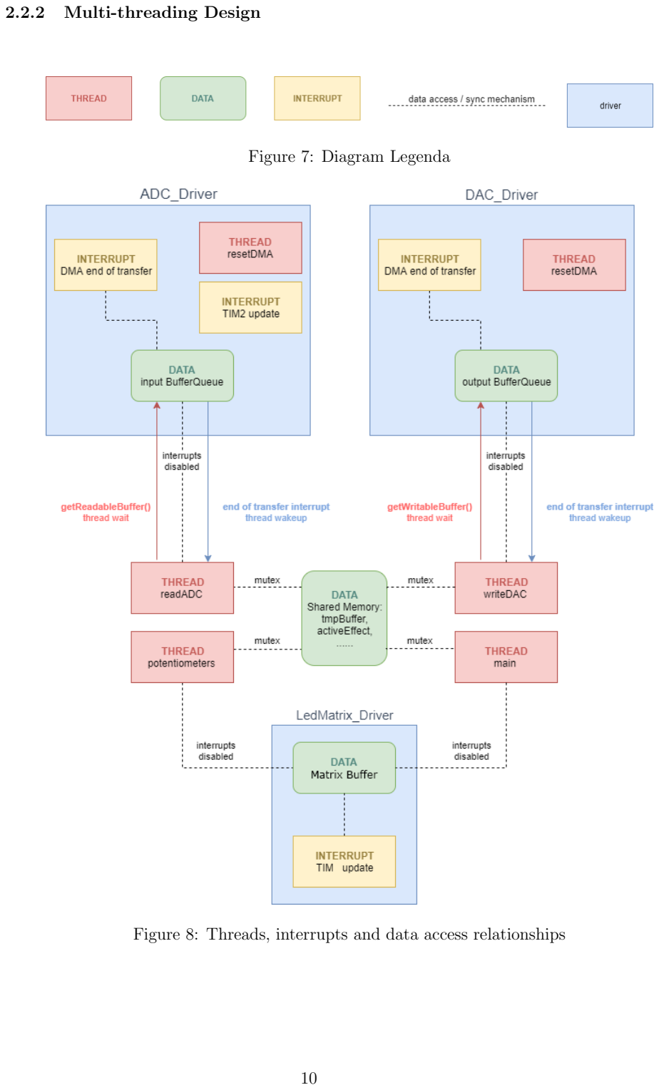
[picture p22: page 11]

### 2.2.2 Multi-threading Design

Figure 7: Diagram Legenda

Figure 8: Threads, interrupts and data access relationships

The application is realized with 6 threads. The two most important threads | readADC | and
writeDAC | have the highest priority because they should be responsive to allow the audio
stream without lags or skipping buffers.
readADC | reads from a buffer queue in the | ADC Driver | , which is filled with audio sampled from
ADC at 44,1 kHZ, in a similar way | writeDAC | writes in the buffer queue of the | DAC Driver | .
When | getReadableBuffer() | is called the | readADC | thread is put in a wait state until a buffer
is available to be read, when the DMA has finished the transfer.
In a similar way, when | getWritableBuffer() | is called, the | writeDAC | thread is put in wait
until a buffer is available to be wrote.

In order for the threads to be synchronized, it is required that the samples in input, and the
ones in output are read/wrote at the same frequency, which in this case is 44,1 Khz, because
it is a standard sampling frequency for audio.
The input/output buffer queues are accessed by interrupts (DMA) and threads ( readADC | / writeDAC | ),
so to avoid concurrency problems, interrupts are disabled when accessing from the thread.

The potentiometer and main thread spin at fixed rates and are responsible for reading potentiometers values from the ADC and for checking the button to switch effect/audio source.

The two | resetDMA | threads are responsible to restart the DMAs in case the process stops
because no buffer was available to be read/wrote.

### 2.2.3 Drivers

In order to hide the low level handling of peripheral registers and the logic required, we wrote some classes that act as drivers, providing higher level methods to use the ADC, DAC and Led Matrix. The drivers are implemented as static classes.

### 2.2.3.1 TIMx Configuration

Since drivers use hardware timer interrupts, we will show how the right frequency of the interrupts is obtained.

Starting from the internal clock frequency (168MHz), we pass through the AHB Prescaler and the AHB1 Prescaler, so the initial timer frequency is:

fT IMx =

fclk,int
AHB P SC · AP B1 P SC =

168MHz
4

= 42Mhz

Then, the frequency can be further prescaled setting the 16 bit prescaler (TIMx PSC) and the auto-reload register (TIMx ARR), according to this formula:

fevent =

fT IMx
(T IMx P SC + 1) · (T IMx ARR + 1)

### 2.2.3.2 ADC Driver

The peripherals used by the driver are ADC1, ADC2, TIM2, DMA2.

ADC2 is configured in DMA mode, single conversion triggered from the TIM2 update event and the channel is connected to the audio buffer input circuit.

TIM2’s update frequency is set according to this formula, which was explained in the TIMx Configuration section:

fupdate =

fT IM2
(T IM2 P SC + 1) · (T IM2 ARR + 1) =

42MHz
(16 + 1) · (55 + 1) = 44.1kHz
DMA2 is set in peripherals to memory mode to fill | AUDIO BUFFERS SIZE | number of samples
of the input buffer queue.

The ADC resolution is 12 bits, so the values of the samples are in range from 0 to 2¹²−1 = 4095

The driver acts like a producer of audio buffers in the input queue. If the queue is full and a new buffer cannot be added, the DMA stops, so there is a thread that spins in the background to restart the DMA as soon as the queue is free again.

ADC Driver provides access to the reader thread through the following method:

const unsigned short * ADC_Driver :: getReadableBuffer ( miosix :: Thread * readerThread )

The reader thread is set in wait state if a buffer is not available to be read, it will be woken up later, when the DMA end of transfer interrupt occurs and the buffer is filled again.

The driver has also methods to perform single ADC conversions or multiple conversions with a low pass filter. For these functionalities ADC1 is used:

unsigned short ADC_Driver :: singleConversion ( unsigned short channel ); unsigned short ADC_Driver :: filterConversions ( unsigned short channel );

### 2.2.3.3 DAC Driver

The DAC used is the CS43L22, which is already mounted on the discovery board.
It operates in I2S mode, for which the SPI3 peripheral is used with the internal audio PLL set to 44,1 kHz.
DMA1 is set in memory to peripheral mode to send | AUDIO BUFFERS SIZE | number of samples
from the the output buffer queue to the DAC through I2S.
I2S protocol uses 16 bit unsigned PCM samples, so the values are in range from 0 to 2¹⁶ − 1 = 65535

The driver acts like a consumer of audio buffers in the output queue. If there is no buffer available in the queue, the DMA stops, so there is a thread that spins in the background to restart it as soon as the queue is filled again.

DAC Driver provides access to the writer thread through the following method:

unsigned short * DAC_Driver :: getWritableBuffer ( miosix :: Thread * writerThread )

The writer thread is set in wait state if a buffer is not available to be wrote, it will be woken up later, when the DMA end of transfer interrupt occurs and the queue is free again.

The DAC output is connected to audio jack on the discovery board, which is then connected to the speaker amplifier on the main PCB with a jack cable.

### 2.2.3.4 Led Matrix Driver

The Led Matrix serves as the output viewer of this project. To better handle this component,
Led Matrix Driver | was implemented.
Led Matrix Driver | provides access to the writer thread through the following method:

void LedMatrix_Driver :: setString ( const std :: string & str );

This method writes the led values in a buffer according to the string given as input.
To write in the buffer, a | FastInterruptDisableLock | is needed to avoid concurrency problems
with respect to the other threads which access this method.

Then, the method

void LedMatrix_Driver :: writeLeds ();

lights up the leds based on the buffer’s values, one row at a time.

As we can see in the Circuits section of the PCB, there are PNP transistors only for the rows, so we can light up at most one entire row to avoid damaging the board, since the maximum current output allowed by the board is 100mA.
Running this on a separate thread was not a good choice, since the other threads affected its behaviour in a visible manner, so we chose to implement an Interrupt Routine to achieve a constant refresh rate of the led matrix.
So we used an internal timer (TIM5) to trigger the IRQ. First of all, we configured TIM5’s frequency according to this formula, which was explained in the TIMx Configuration section:

fupdate =

fT IM5
(T IM5 P SC + 1) · (T IM5 ARR + 1) =

42MHz
(349 + 1) · (239 + 1) = 500Hz

This means that each row of leds is refreshed in such a way that we can see all of the rows active at the same time.
Note that, since an Interrupt call refreshes a single row of the led matrix, lowering the frequency value makes the view unstable.

### 2.2.4 Audio Chain

The audio chain is mainly implemented in the | readADC | / writeDAC | threads.
readADC | thread copies buffers from the | ADC Driver | into a shared buffer, which is accessed
with mutex protection because it is also used by | writeDAC | thread.
It also converts values from unsigned 12 bit to floating point.
writeDAC | is the thread that performs the actual DSP on the buffer, before writing it to the
DAC Driver | .
If the audio source is set to | ADC , the shared buffer is used as input for the active effect DSP
algorithm.
If the audio source is set to | Synthesizer | the shared buffer is not used, because input samples
are generated by the thread and then fed into the active DSP algorithm.
Then samples are converted from floating point to unsigned 16 bit PCM and sent to the
DAC Driver | .
The number of samples in each buffer can be changed by defining | AUDIO BUFFERS SIZE | , which
is currently set to 512.

### 2.2.5 DSP Effects

The synth and the DSP effects are all implemented by extending a base class | AudioEffect | ,
that provides virtual methods that can be overridden to create different effects.
In particular the DSP algorithm is executed in the method:

virtual void AudioEffect :: writeNextBuffer ( float * inBuff , float * outBuff );

The default implementation just copies | inBuff | into | outBuff | , applying no effect.

This design allows to easily implement different effects, focusing only on the DSP part and avoiding to handle all the audio chain, as well as the controls updating from the potentiometers.

The effects included in this demonstration are a Delay, a Filter and a Tremolo.

### 2.2.5.1 Delay

The delay effect is obtained thanks to a circular buffer, which is continuously refilled from the beginning once is full.
This buffer has a size that is a multiple of | AUDIO BUFFERS SIZE | , and it is used to keep in
memory samples from past buffers.
When producing the next buffer, samples from the delay buffer are added to the input, multiplied by a feedback parameter.
The maximum delay time depends on the size of the circular buffer, and can be computed as:

Tmax =

buffer size

fsampling

In this case, the circular buffer size is set to:

Tmax =

k · | AUDIO BUFFERS SIZE
44.1kHz | =

45 · 512
44.1kHz = 522ms

The actual delay time, as well as the feedback are left as parameters controllable with potentiometers.

### 2.2.5.2 Filter

The filter effect implements a simple low-pass, band-pass and high pass filter. Controllable parameters are cutoff frequency and resonance.
The DSP algorithm implemented is from Paul Kellett and can be found at: https://www.musicdsp.org/en/latest/Filters/29-resonant-filter.html

### 2.2.5.3 Tremolo

The tremolo effect applies a modulation on the signal amplitude, which is controlled by a software LFO (low frequency oscillator).
The signal samples are multiplied by a factor which is generated by the LFO and the speed can be controlled as parameter.

### 2.2.5.4 Synthesizer

We added a wavetable synthesizer to be used as an audio source.
it is implemented by extending the | AudioEffect | class in a way similar to the DSP effects,
but since it generates the samples from scratch it does not read from | inBuffer | , but writes to
outBuffer | .

Wavetables are pre-computed to make the real-time computations faster, so when the samples are generated, values from the wavetables are used, with proper stretching according to the desired sound frequency.

The synthesizer has 3 independent oscillators, each one using a different wavetable:

- Sine
- Triangle
- Square Wave

Those waveforms are added together and multiplied by the respective amplitude, in order to generate the output samples.
Each individual oscillator and its parameters can be controlled with potentiometers.

Controllable parameters are:

- Frequency
- Amplitude
- Speed
- Mode

Speed parameter controls the speed at which the selected pattern is played.
Mode allows to select a pattern for the oscillator, such as continuous note, scale, random notes, octaves and so on.

## 3 Conclusions

This project covered the development of a system in which multiple audio sources could go through different digital audio effects, all in a real-time environment and with an enhanced user experience brought by a custom PCB.

We experienced some noise in the audio sampled from ADC, and we couldn’t remove it com-pletely, but overall, we can say that our initial goal was reached and we built a solid base for future improvements.

The | AudioEffect | class is very easy to extend, so adding a new digital audio effect and viewing
it in the led matrix, is a very simple task, and this applies also to adding other audio sources.

### 3.1 Future Improvements

We could implement audio effects which require the usage of a FFT to expand the pool of options.

Another possible improvement would be adding an anti-aliasing filter on the audio signal before the ADC sampling, which could maybe solve the noise problem mentioned before.

Also, we could use a cleaner power supply and a better analog/digital power separation on the PCB.

Finally, an improvement to the user experience would be a better handling of controls shown in the led matrix.

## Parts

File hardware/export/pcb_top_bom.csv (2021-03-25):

Comment | Designator | Footprint | LCSC Part #
1.8k | R4 R20 R21 R22 R23 R24 R25 R26 R27 R28 | R0805
100n | C8 C10 | C0805
270 | R5 R6 R7 R8 R9 R10 R11 R12 R13 R14 R15 R16 R17 R18 R19 | R0805
PNP SOT23 | T1 T2 T3 T4 T5 T6 T7 T8 T9 T10 | SOT23-BEC
led 0805 | LED1 LED2 LED3 LED4 LED5 LED6 LED7 LED8 LED9 LED10 LED11 LED12 LED13 LED14 LED15 LED16 LED17 LED18 LED19 LED20 LED21 LED22 LED23 LED24 LED25 LED26 LED27 LED28 LED29 LED30 LED31 LED32 LED33 LED34 LED35 LED36 LED37 LED38 LED39 LED40 LED41 LED42 LED43 LED44 LED45 LED46 LED47 LED48 LED49 LED50 LED51 LED52 LED53 LED54 LED55 LED56 LED57 LED58 LED59 LED60 LED61 LED62 LED63 LED64 LED65 LED66 LED67 LED68 LED69 LED70 LED71 LED72 LED73 LED74 LED75 LED76 LED77 LED78 LED79 LED80 LED81 LED82 LED83 LED84 LED85 LED86 LED87 LED88 LED89 LED90 LED91 LED92 LED93 LED94 LED95 LED96 LED97 LED98 LED99 LED100 LED101 LED102 LED103 LED104 LED105 LED106 LED107 LED108 LED109 LED110 LED111 LED112 LED113 LED114 LED115 LED116 LED117 LED118 LED119 LED120 LED121 LED122 LED123 LED124 LED125 LED126 LED127 LED128 LED129 LED130 LED131 LED132 LED133 LED134 LED135 LED136 LED137 LED138 LED139 LED140 LED141 LED142 LED143 LED144 LED145 LED146 LED147 LED148 LED149 LED150 | CHIPLED_0805

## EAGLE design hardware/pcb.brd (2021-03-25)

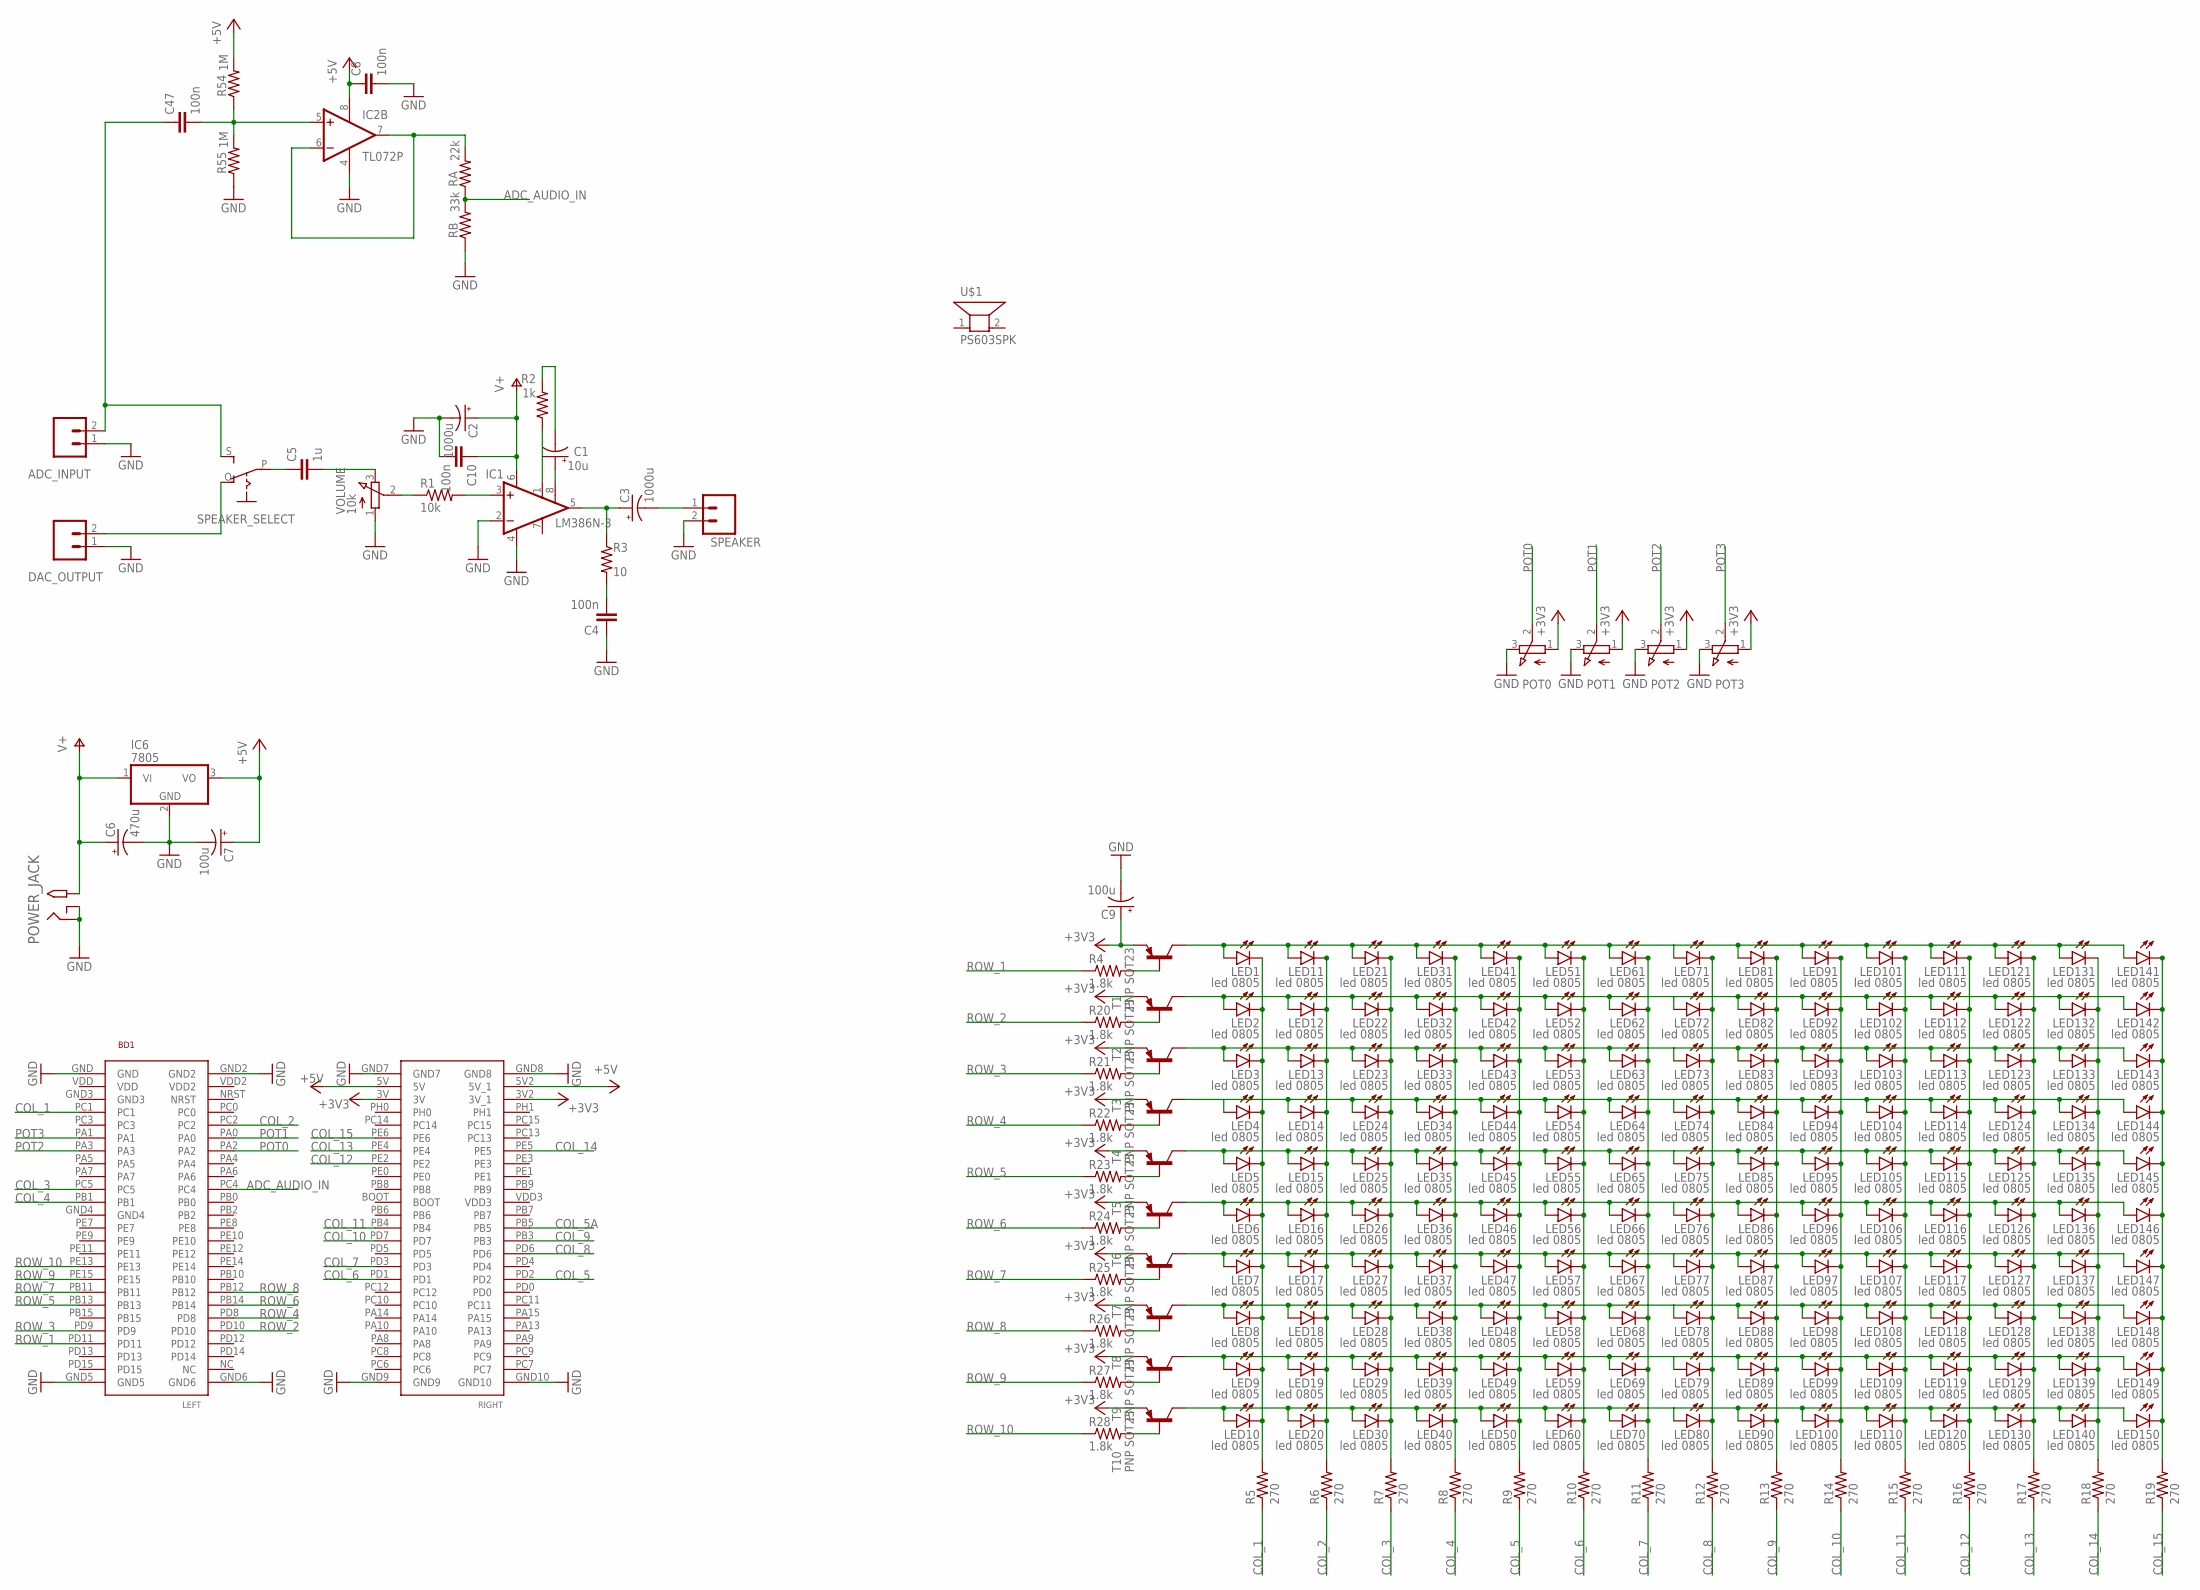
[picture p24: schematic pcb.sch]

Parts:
ADC_INPUT: M02; 02P
BD1: STM32F4-DISCOVERY; STM32F407VG
C1: 10u; E5-6
C2, C3: 1000u; E5-13
C4, C47: 100n; C5B3.5
C5: 1u; C050-035X075
C6: 470u; E5-6
C7, C9: 100u; E5-6
C8, C10: 100n; C0805
DAC_OUTPUT: M02; 02P
IC1: LM386N-3; DIL08
IC2: TL072P; DIL08
IC6: 7805; TO220H
LED1, LED2, LED3, LED4, LED5, LED6, LED7, LED8, LED9, LED10, LED11, LED12, LED13, LED14, LED15, LED16, LED17, LED18, LED19, LED20, LED21, LED22, LED23, LED24, LED25, LED26, LED27, LED28, LED29, LED30, LED31, LED32, LED33, LED34, LED35, LED36, LED37, LED38, LED39, LED40, LED41, LED42, LED43, LED44, LED45, LED46, LED47, LED48, LED49, LED50, LED51, LED52, LED53, LED54, LED55, LED56, LED57, LED58, LED59, LED60, LED61, LED62, LED63, LED64, LED65, LED66, LED67, LED68, LED69, LED70, LED71, LED72, LED73, LED74, LED75, LED76, LED77, LED78, LED79, LED80, LED81, LED82, LED83, LED84, LED85, LED86, LED87, LED88, LED89, LED90, LED91, LED92, LED93, LED94, LED95, LED96, LED97, LED98, LED99, LED100, LED101, LED102, LED103, LED104, LED105, LED106, LED107, LED108, LED109, LED110, LED111, LED112, LED113, LED114, LED115, LED116, LED117, LED118, LED119, LED120, LED121, LED122, LED123, LED124, LED125, LED126, LED127, LED128, LED129, LED130, LED131, LED132, LED133, LED134, LED135, LED136, LED137, LED138, LED139, LED140, LED141, LED142, LED143, LED144, LED145, LED146, LED147, LED148, LED149, LED150: led 0805; CHIPLED_0805
POT0, POT1, POT2, POT3: 3RP/1610N
POWER_JACK: 2.1MMJACKTHM; PJ-102A
R1: 10k; 0207/10
R2: 1k; 0207/10
R3: 10; 0207/10
R4, R20, R21, R22, R23, R24, R25, R26, R27, R28: 1.8k; R0805
R5, R6, R7, R8, R9, R10, R11, R12, R13, R14, R15, R16, R17, R18, R19: 270; R0805
R54, R55: 1M; 0207/10
RA: 22k; 0207/10
RB: 33k; 0207/10
SPEAKER: M02; 02P
SPEAKER_SELECT: EG1218S; EG1218
T1, T2, T3, T4, T5, T6, T7, T8, T9, T10: PNP SOT23; SOT23-BEC
U$1: PS603SPK; PS603
VOLUME: 10k; 3RP/1610N

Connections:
+3V3: BD1.3V, BD1.3V2 (3V_1), C9.+, POT0.1 (A), POT1.1 (A), POT2.1 (A), POT3.1 (A), T1.E, T2.E, T3.E, T4.E, T5.E, T6.E, T7.E, T8.E, T9.E, T10.E
+5V: BD1.5V, BD1.5V2 (5V_1), C7.+, C8.1, IC2.8 (V+), IC6.3 (VO), R54.2
ADC_AUDIO_IN: BD1.PC4, RA.1, RB.2
COL_1: BD1.PC1, R5.1
COL_2: BD1.PC2, R6.1
COL_3: BD1.PC5, R7.1
COL_4: BD1.PB1, R8.1
COL_5: BD1.PD2, R9.1
COL_5A: BD1.PB5
COL_6: BD1.PD1, R10.1
COL_7: BD1.PD3, R11.1
COL_8: BD1.PD6, R12.1
COL_9: BD1.PB3, R13.1
COL_10: BD1.PD7, R14.1
COL_11: BD1.PB4, R15.1
COL_12: BD1.PE2, R16.1
COL_13: BD1.PE4, R17.1
COL_14: BD1.PE5, R18.1
COL_15: BD1.PE6, R19.1
GND: ADC_INPUT.1, BD1.GND, BD1.GND2, BD1.GND5, BD1.GND6, BD1.GND7, BD1.GND8, BD1.GND9, BD1.GND10, C2.-, C4.1, C6.-, C7.-, C8.2, C9.-, C10.2, DAC_OUTPUT.1, IC1.2 (-IN), IC1.4 (GND), IC2.4 (V-), IC6.2 (GND), POT0.3 (E), POT1.3 (E), POT2.3 (E), POT3.3 (E), POWER_JACK.RING, POWER_JACK.RING_SW, R55.1, RB.1, SPEAKER.2, VOLUME.1 (A)
GUITAR_BUFFER: IC2.6 (-IN), IC2.7 (OUT), RA.2
unnamed: LED1.C, LED2.C, LED3.C, LED4.C, LED5.C, LED6.C, LED7.C, LED8.C, LED9.C, LED10.C, R5.2
unnamed: C5.2, VOLUME.3 (E)
unnamed: LED11.C, LED12.C, LED13.C, LED14.C, LED15.C, LED16.C, LED17.C, LED18.C, LED19.C, LED20.C, R6.2
unnamed: LED21.C, LED22.C, LED23.C, LED24.C, LED25.C, LED26.C, LED27.C, LED28.C, LED29.C, LED30.C, R7.2
unnamed: LED31.C, LED32.C, LED33.C, LED34.C, LED35.C, LED36.C, LED37.C, LED38.C, LED39.C, LED40.C, R8.2
unnamed: LED41.C, LED42.C, LED43.C, LED44.C, LED45.C, LED46.C, LED47.C, LED48.C, LED49.C, LED50.C, R9.2
unnamed: LED51.C, LED52.C, LED53.C, LED54.C, LED55.C, LED56.C, LED57.C, LED58.C, LED59.C, LED60.C, R10.2
unnamed: LED61.C, LED62.C, LED63.C, LED64.C, LED65.C, LED66.C, LED67.C, LED68.C, LED69.C, LED70.C, R11.2
unnamed: LED71.C, LED72.C, LED73.C, LED74.C, LED75.C, LED76.C, LED77.C, LED78.C, LED79.C, LED80.C, R12.2
unnamed: LED81.C, LED82.C, LED83.C, LED84.C, LED85.C, LED86.C, LED87.C, LED88.C, LED89.C, LED90.C, R13.2
unnamed: LED91.C, LED92.C, LED93.C, LED94.C, LED95.C, LED96.C, LED97.C, LED98.C, LED99.C, LED100.C, R14.2
unnamed: LED101.C, LED102.C, LED103.C, LED104.C, LED105.C, LED106.C, LED107.C, LED108.C, LED109.C, LED110.C, R15.2
unnamed: LED111.C, LED112.C, LED113.C, LED114.C, LED115.C, LED116.C, LED117.C, LED118.C, LED119.C, LED120.C, R16.2
unnamed: LED121.C, LED122.C, LED123.C, LED124.C, LED125.C, LED126.C, LED127.C, LED128.C, LED129.C, LED130.C, R17.2
unnamed: LED131.C, LED132.C, LED133.C, LED134.C, LED135.C, LED136.C, LED137.C, LED138.C, LED139.C, LED140.C, R18.2
unnamed: LED141.C, LED142.C, LED143.C, LED144.C, LED145.C, LED146.C, LED147.C, LED148.C, LED149.C, LED150.C, R19.2
unnamed: LED1.A, LED11.A, LED21.A, LED31.A, LED41.A, LED51.A, LED61.A, LED71.A, LED81.A, LED91.A, LED101.A, LED111.A, LED121.A, LED131.A, LED141.A, T1.C
unnamed: R25.2, T7.B
unnamed: R26.2, T8.B
unnamed: LED7.A, LED17.A, LED27.A, LED37.A, LED47.A, LED57.A, LED67.A, LED77.A, LED87.A, LED97.A, LED107.A, LED117.A, LED127.A, LED137.A, LED147.A, T7.C
unnamed: LED8.A, LED18.A, LED28.A, LED38.A, LED48.A, LED58.A, LED68.A, LED78.A, LED88.A, LED98.A, LED108.A, LED118.A, LED128.A, LED138.A, LED148.A, T8.C
unnamed: LED9.A, LED19.A, LED29.A, LED39.A, LED49.A, LED59.A, LED69.A, LED79.A, LED89.A, LED99.A, LED109.A, LED119.A, LED129.A, LED139.A, LED149.A, T9.C
unnamed: LED10.A, LED20.A, LED30.A, LED40.A, LED50.A, LED60.A, LED70.A, LED80.A, LED90.A, LED100.A, LED110.A, LED120.A, LED130.A, LED140.A, LED150.A, T10.C
unnamed: ADC_INPUT.2, C47.1, SPEAKER_SELECT.S
unnamed: DAC_OUTPUT.2, SPEAKER_SELECT.O
unnamed: R1.1, VOLUME.2 (S)
unnamed: IC1.3 (+IN), R1.2
unnamed: C1.+, IC1.8 (GAIN)
unnamed: IC1.1 (GAIN), R2.1
unnamed: C1.-, R2.2
unnamed: C3.+, IC1.5 (OUT), R3.1
unnamed: C3.-, SPEAKER.1
unnamed: C4.2, R3.2
unnamed: C5.1, SPEAKER_SELECT.P
unnamed: R4.2, T1.B
unnamed: LED2.A, LED12.A, LED22.A, LED32.A, LED42.A, LED52.A, LED62.A, LED72.A, LED82.A, LED92.A, LED102.A, LED112.A, LED122.A, LED132.A, LED142.A, T2.C
unnamed: R20.2, T2.B
unnamed: LED3.A, LED13.A, LED23.A, LED33.A, LED43.A, LED53.A, LED63.A, LED73.A, LED83.A, LED93.A, LED103.A, LED113.A, LED123.A, LED133.A, LED143.A, T3.C
unnamed: R21.2, T3.B
unnamed: LED4.A, LED14.A, LED24.A, LED34.A, LED44.A, LED54.A, LED64.A, LED74.A, LED84.A, LED94.A, LED104.A, LED114.A, LED124.A, LED134.A, LED144.A, T4.C
unnamed: R22.2, T4.B
unnamed: LED5.A, LED15.A, LED25.A, LED35.A, LED45.A, LED55.A, LED65.A, LED75.A, LED85.A, LED95.A, LED105.A, LED115.A, LED125.A, LED135.A, LED145.A, T5.C
unnamed: R23.2, T5.B
unnamed: LED6.A, LED16.A, LED26.A, LED36.A, LED46.A, LED56.A, LED66.A, LED76.A, LED86.A, LED96.A, LED106.A, LED116.A, LED126.A, LED136.A, LED146.A, T6.C
unnamed: R24.2, T6.B
unnamed: R27.2, T9.B
unnamed: R28.2, T10.B
unnamed: C47.2, IC2.5 (+IN), R54.1, R55.2
POT0: BD1.PA2, POT0.2 (S)
POT1: BD1.PA0, POT1.2 (S)
POT2: BD1.PA3, POT2.2 (S)
POT3: BD1.PA1, POT3.2 (S)
ROW_1: BD1.PD11, R4.1
ROW_2: BD1.PD10, R20.1
ROW_3: BD1.PD9, R21.1
ROW_4: BD1.PD8, R22.1
ROW_5: BD1.PB13, R23.1
ROW_6: BD1.PB14, R24.1
ROW_7: BD1.PB11, R25.1
ROW_8: BD1.PB12, R26.1
ROW_9: BD1.PE15, R27.1
ROW_10: BD1.PE13, R28.1
V+: C2.+, C6.+, C10.1, IC1.6 (VS), IC6.1 (VI), POWER_JACK.TIP

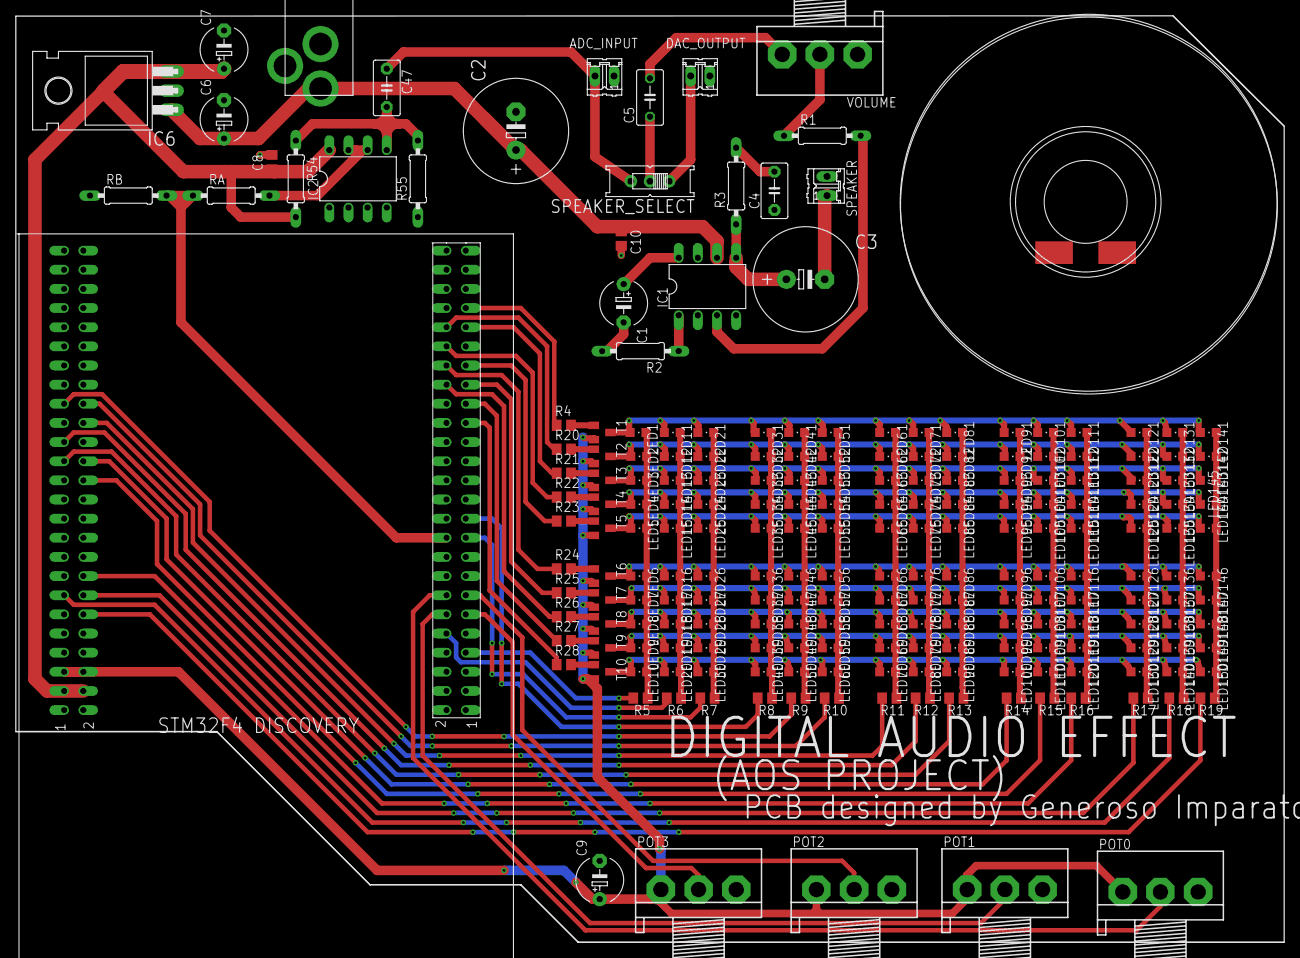
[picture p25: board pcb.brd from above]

Board: 2 copper layers, 168.3 x 122.9 mm, 218 parts (0 on the bottom side), 83 nets.

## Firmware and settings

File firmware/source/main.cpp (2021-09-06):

#include <miosix.h>
#include <mutex>
#include "config.h"
#include "AudioChain.h"
#include "Button.h"
#include "ADC_Driver/ADC_Driver.h"
#include "DAC_Driver/DAC_Driver.h"
#include "LedMatrix_Driver/LedMatrix_Driver.h"

using namespace miosix;

int main()
{
	LedMatrix_Driver::init();

	AudioChain::init();

	ADC_Driver::init();
	DAC_Driver::init();
	DAC_Driver::setVolume(0);
	
	AudioChain::startThreads();


	Button<GPIOA_BASE,0> button;
	//main loop
    while(true)
    {
		button.check();	
		Thread::sleep(BUTTONS_REFRESH_PERIOD);
    }
}

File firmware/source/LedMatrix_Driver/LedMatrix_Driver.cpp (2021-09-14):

#include "LedMatrix_Driver.h"
#include "Leds_Gpios.h" // For Gpio namespace
#include "Leds_Chars.h" // For hardcoded characters for the buffer
#include <cctype> // For toupper()

using namespace miosix;

LedString bufStr {}; //Buffer

std::vector<GpioPin> ROWS;
std::vector<GpioPin> COLS;

static unsigned short rowCount = 0;

/*
	Since the led matrix is 10x15, we can divide it into logical areas:
		- Horizontal layers: these are the TWO 5x15 sub-matrices
		- Vertical layers: these are the FIVE 10x3 sub-matrices
*/

/*
	This function does the following actions:
		- Checks that we have at most 5 characters per layer
		- Switches layers according to the current buffer status
*/
void checkHorizontalLayer(unsigned short &letterCount, unsigned short &horizontalLayerCount, unsigned short &verticalLayerCount){
	if(letterCount == LED_MAX_CHARS/2 && horizontalLayerCount <= LED_HORIZONTAL_LAYERS-1){
		horizontalLayerCount++;
		verticalLayerCount = 0;
	}
}

/*
	This function does the following actions:
		- Checks that we don't surpass the vertical layer's bound
*/
void checkVerticalLayer(unsigned short &verticalLayerCount){
	if (verticalLayerCount < LED_VERTICAL_LAYERS - 1){
		verticalLayerCount++;
	}
}

/*
	This method configures the TIM5 timer
*/
void LedMatrix_Driver::configureTIM5(void){
    // enable TIM5 clock (bit 7)
    RCC->APB1ENR|= RCC_APB1ENR_TIM5EN;           

    //300 Hz
    TIM5->PSC = 349;
    TIM5->ARR = 399;

    /* Reset the MMS Bits */
    TIM5->CR2 &= (uint16_t)~TIM_CR2_MMS;
    /* Select the TRGO source */
    TIM5->CR2 |=  TIM_CR2_MMS_1; //010: UPDATE EVENT       

    // Update Interrupt Enable
    TIM5->DIER |= TIM_DIER_UIE;

    // enable TIM5 IRQ from NVIC
    NVIC_SetPriority(TIM5_IRQn, 0);//Low priority for LedMatrix
    NVIC_EnableIRQ(TIM5_IRQn);

    // Enable Timer 5 module (Counter ENable, bit 0)
    TIM5->CR1 |= TIM_CR1_CEN;
	TIM5->CR1 &= ~(TIM_CR1_UDIS); //Update Enable
	TIM5->CR1 &= ~(TIM_CR1_DIR);// Upcounting
}


void LedMatrix_Driver::init(){
	// Puts the GPIOs in 2 Vectors to facilitate their usage
	fillVectors();

	// Set OUTPUT mode on every led
	setGpiosMode();

	// Turn OFF all leds since setting their mode to OUTPUT turns them on
	turnOffAllLeds();
	
	// TIM5 initialization
	configureTIM5();
}


/*
	This method fills two vectors (one for the rows and one for the columns) with the relative GPIOs
*/
void LedMatrix_Driver::fillVectors(){
	
	ROWS.push_back(ROW1::getPin());
	ROWS.push_back(ROW2::getPin());
	ROWS.push_back(ROW3::getPin());
	ROWS.push_back(ROW4::getPin());
	ROWS.push_back(ROW5::getPin());
	ROWS.push_back(ROW6::getPin());
	ROWS.push_back(ROW7::getPin());
	ROWS.push_back(ROW8::getPin());
	ROWS.push_back(ROW9::getPin());
	ROWS.push_back(ROW10::getPin());

	COLS.push_back(COL1::getPin());
	COLS.push_back(COL2::getPin());
	COLS.push_back(COL3::getPin());
	COLS.push_back(COL4::getPin());
	COLS.push_back(COL5::getPin());
	COLS.push_back(COL6::getPin());
	COLS.push_back(COL7::getPin());
	COLS.push_back(COL8::getPin());
	COLS.push_back(COL9::getPin());
	COLS.push_back(COL10::getPin());
	COLS.push_back(COL11::getPin());
	COLS.push_back(COL12::getPin());
	COLS.push_back(COL13::getPin());
	COLS.push_back(COL14::getPin());
	COLS.push_back(COL15::getPin());
}


/* 
	This method sets OUTPUT mode to every GPIO in the two vectors
*/
void LedMatrix_Driver::setGpiosMode(){

	for (int i = 0; i < LED_MATRIX_ROWS; i++){
		ROWS[i].mode(Mode::OUTPUT);
	}
	for (int i = 0; i < LED_MATRIX_COLUMNS; i++){
		COLS[i].mode(Mode::OUTPUT);
	}
}

void LedMatrix_Driver::turnOffAllLeds(){
	rowsOff();
	columnsOff();
}

void LedMatrix_Driver::rowsOff(){
	for (unsigned int i = 0; i < ROWS.size(); i++){
		ROWS[i].high();
	}
}

void LedMatrix_Driver::columnsOff(){
	for (unsigned int i = 0; i < COLS.size(); i++){
		COLS[i].high();
	}
}

/* 	
	This method writes a character in a 5x3 sub-matrix, in a position given by the following parameters: 
		ledHorizontalLayer: can have values 0-1 
			when 0, it targets rows 0-4
			when 1, it targets rows 5-9
		ledVerticalLayer: can have value 0-4
			when 0, it targets columns 0-2
			when 1, it targets columns 3-5
			...
			when 4, it targets columns 12-14
*/
void LedMatrix_Driver::setChar(LedChar ledChar, unsigned short ledHorizontalLayer, unsigned short ledVerticalLayer){
	for (int i = LED_SUBMATRIX_ROWS*ledHorizontalLayer; i < LED_MATRIX_ROWS; i++){
		for (int j = LED_SUBMATRIX_COLUMNS*ledVerticalLayer; j < LED_MATRIX_COLUMNS; j++){
			if (!bufStr[i][j] && (i - LED_SUBMATRIX_ROWS*ledHorizontalLayer) < LED_SUBMATRIX_ROWS && (j - LED_SUBMATRIX_COLUMNS*ledVerticalLayer) < LED_SUBMATRIX_COLUMNS)		
				bufStr[i][j] += ledChar[i - LED_SUBMATRIX_ROWS*ledHorizontalLayer][j - LED_SUBMATRIX_COLUMNS*ledVerticalLayer];
		}
	}
}
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

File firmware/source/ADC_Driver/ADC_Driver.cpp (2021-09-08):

#include "ADC_Driver.h"

using namespace miosix;

const unsigned short    ADC_Driver::potChannels[POTS_COUNT] = {2,8,3,1};

AudioBufferQueue*       ADC_Driver::dmaBuffer;
miosix::Thread*         ADC_Driver::waitingThread;
miosix::Thread*         ADC_Driver::restartThread;
bool                    ADC_Driver::dmaRefillWaiting = false;

unsigned short ADC_Driver::buffer[AUDIO_BUFFERS_SIZE];


typedef Gpio<GPIOA_BASE,2> pot0;
typedef Gpio<GPIOB_BASE,0> pot1;
typedef Gpio<GPIOA_BASE,3> pot2;
typedef Gpio<GPIOA_BASE,1> pot3;
typedef Gpio<GPIOC_BASE,4> audioInput;


void ADC_Driver::init()
{
    dmaBuffer = new AudioBufferQueue();

    pot0::mode(Mode::INPUT_ANALOG);
    pot1::mode(Mode::INPUT_ANALOG);
    pot2::mode(Mode::INPUT_ANALOG);
    pot3::mode(Mode::INPUT_ANALOG);
    audioInput::mode(Mode::INPUT_ANALOG);

    {
        FastInterruptDisableLock dLock;
        //Enable DMA2 clock
        RCC->AHB1ENR |= RCC_AHB1ENR_DMA2EN;
        RCC_SYNC();
    }
	//enable ADC1 clock
	RCC->APB2ENR |= RCC_APB2ENR_ADC1EN;
    RCC_SYNC();

    ADC->CCR |= (1<<16)|(1<<17);

   	//activate ADC1
    ADC1->CR2 = ADC_CR2_ADON;

    configureADC2();

    //wait
    miosix::delayMs(500);

    NVIC_SetPriority(DMA2_Stream2_IRQn,2);//High priority for DMA
    NVIC_EnableIRQ(DMA2_Stream2_IRQn);

    dmaRestart();

    /*unsigned short *buff;
    unsigned int size;
    dmaBuffer->tryGetWritableBuffer(buff);
   
    for(int i=0; i<AUDIO_BUFFERS_SIZE; i++)
    {
        buff[i] = i*60000/AUDIO_BUFFERS_SIZE;
    }
    dmaBuffer->bufferFilled(AUDIO_BUFFERS_SIZE);*/

    configureTIM2();

    restartThread = Thread::create(&ADC_Driver::threadMain, 256, 0);
}

void ADC_Driver::configureTIM2(void)
{
    // enable TIM2 clock (bit0)
    RCC->APB1ENR |= (1 << 0);           

    //44.1 Khz
    TIM2->PSC = 16;
    TIM2->ARR = 55;

    /* Reset the MMS Bits */
    TIM2->CR2 &= (uint16_t)~TIM_CR2_MMS;
    /* Select the TRGO source */
    TIM2->CR2 |=  TIM_CR2_MMS_1; //UPDATE EVENT       

    // Update Interrupt Enable
    //TIM2->DIER |= (1 << 0);

    // enable TIM2 IRQ from NVIC
    //NVIC_EnableIRQ(TIM2_IRQn);

    // Enable Timer 2 module (CEN, bit0)
    TIM2->CR1 |= (1 << 0);
}

void ADC_Driver::configureADC2()
{
    RCC->APB2ENR|=RCC_APB2ENR_ADC2EN;  //ADC2 clock enable
    RCC_SYNC();
    ADC2->SQR1&=~ADC_SQR1_L;                         
        
    //set number of conversions per sequence to 1
    ADC2->SQR3&=~ADC_SQR3_SQ1;                   
        
    //clear channel select bits
    ADC2->SQR3|=14;         //set channel
    ADC2->CR1 &= ~ADC_CR1_SCAN; //SCAN mode disabled    
    ADC2->CR2 &= ~ADC_CR2_CONT; //Disable continuous conversion
                    
    ADC1->SMPR1 =   0xFFFFFFFF;
    ADC1->SMPR2 =   0xFFFFFFFF; 
    
    //Trigger on Rising edge
    ADC2->CR2 &=  ~(1<<29);
    ADC2->CR2 |= (1<<28);   
    
    //External Event TIM2 TRGO [0110]
    const uint32_t TIM2_TRGO = ADC_CR2_EXTSEL_2 | ADC_CR2_EXTSEL_1; 
    ADC2->CR2 &= ~(ADC_CR2_EXTSEL);   // remove all selections
    ADC2->CR2 |= TIM2_TRGO;
    
    ADC2->CR2|=ADC_CR2_ADON;
 
    //enable DMA
    ADC2->CR2 |= ADC_CR2_DMA;  

    //starts ADC    
    ADC2->CR2|=ADC_CR2_SWSTART;     
}

//performs a single conversion (uses ADC1)
unsigned short ADC_Driver::singleConversion(unsigned short channel)
{
	//single conversion mode
	ADC1->CR1 = 0;

	//select sample time
    ADC1->SMPR1 =   0xFFFFFFFF;
    ADC1->SMPR2 = 	0xFFFFFFFF; //239.5 cycles sample time

    //select number of converions
    ADC1->SQR1 = 0; 		//single conversion

    //select channel
    ADC1->SQR2 = 0;
    ADC1->SQR3 = channel; 		//channel 1

    //start conversion
    ADC1->CR2 |= ADC_CR2_SWSTART;

    //wait for conversion to end
    while((ADC1->SR & ADC_SR_EOC)==0);

    unsigned int result=ADC1->DR;

    return result;
}

unsigned short ADC_Driver::filterConversions(unsigned short channel)
{
    unsigned int filteredValue;

    static ADCFilter<FILTER_SAMLPLES_COUNT> filter;
    for(int i=0; i<FILTER_SAMLPLES_COUNT; i++)
        filteredValue = filter(singleConversion(channel));

    return filteredValue;
}

unsigned short ADC_Driver::filterConversionsPot(unsigned short pot)
{
	if(pot>=POTS_COUNT)
		return 0;

    return filterConversions(potChannels[pot]);
}

/**
 * Waits until a buffer is available for reading
 * \return a readable buffer from dmaBuffer
 */
const unsigned short * ADC_Driver::getReadableBuffer(miosix::Thread* readerThread)
{
    FastInterruptDisableLock dLock;
    waitingThread = readerThread;
    const unsigned short *result;
    unsigned int size;
    while(dmaBuffer->tryGetReadableBuffer(result, size)==false)
    {
        waitingThread->IRQwait();
        {
            FastInterruptEnableLock eLock(dLock);
            Thread::yield();
        }
    }
    return result;
}

//Configure the DMA to do another transfer
bool ADC_Driver::IRQdmaRestart()
{
    unsigned short* buffer;

    DMA2_Stream2->CR = 0;
    DMA2_Stream2->PAR=reinterpret_cast<unsigned int>(&ADC2->DR); 


    if(!dmaBuffer->tryGetWritableBuffer(buffer))
    {   
        dmaRefillWaiting = true;
        //miosix::ledOn();
        return false;
    }
    else    
        DMA2_Stream2->M0AR=reinterpret_cast<unsigned int>(buffer);

    DMA2_Stream2->NDTR=AUDIO_BUFFERS_SIZE;
    DMA2_Stream2->CR=DMA_SxCR_PL_1    | //High priority DMA stream
                     DMA_SxCR_MSIZE_0 | //Read  16bit at a time from ADC2
                     DMA_SxCR_PSIZE_0 | //Write 16bit at a time to RAM
                     DMA_SxCR_MINC    | //Increment RAM pointer
                     DMA_SxCR_TCIE    | //Interrupt on completion
                     DMA_SxCR_CHSEL_0 | //Select channel 1
                     DMA_SxCR_EN;       //Start the DMA

    return true;
}

void ADC_Driver::bufferEmptied()
{
    FastInterruptDisableLock dLock;
    dmaBuffer->bufferEmptied();
}


//Helper function used to start a DMA transfer from non-interrupt code
bool ADC_Driver::dmaRestart()
{
    FastInterruptDisableLock dLock;
    return IRQdmaRestart();
}

void ADC_Driver::adc2Restart()
{
    ADC2->SR &= ~(ADC_SR_OVR);
    ADC2->CR2 |= (ADC_CR2_DMA|ADC_CR2_DDS);
    //clear the overload
    ADC2->SR &= ~(ADC_SR_OVR|ADC_SR_STRT);
    //start the ADC
    ADC2->CR2 |= (uint32_t)ADC_CR2_SWSTART;
}

//DMA end of transer interrupt handler
void ADC_Driver::IRQdmaEndHandler()
{
    DMA2->LIFCR=DMA_LIFCR_CTCIF2  |
                DMA_LIFCR_CTEIF2  |
                DMA_LIFCR_CDMEIF2 |
                DMA_LIFCR_CFEIF2;

    dmaBuffer->bufferFilled(AUDIO_BUFFERS_SIZE);

    ADC2->CR2 &= ~(ADC_CR2_DDS|ADC_CR2_DMA);

    //dmaBuffer->bufferEmptied();

    if(IRQdmaRestart())
    {
        adc2Restart();

        waitingThread->IRQwakeup();
        if(waitingThread->IRQgetPriority()>Thread::IRQgetCurrentThread()->IRQgetPriority())
            Scheduler::IRQfindNextThread();
    }

    //dmaBuffer->bufferEmptied();

}
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

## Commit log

2021-03-20 FIRST WORKING COMMIT
    Firmware:
    -miosix working
    -ADC driver working (single conversion)
    Hardware:
    -PCB quasi finita
    [pcb.brd, pcb.sch, pcb_top_bom.csv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]
2021-03-24 DAC_Driver added
    [EthBoardV2.cfg, anakin.cfg, atsam4l.cfg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]
2021-03-25 PCB final (in production)
    [pcb.brd, pcb.sch, pcb_top_bom.csv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]
2021-03-27 reworked AudioEffect and added/test thread termination
    [main.cpp]
2021-04-08 removed AudioEffect thread start in constructor
    bug after repower
    [main.cpp]
2021-04-15 works on synth + added pot thread
2021-04-15 first trial on matrix led
2021-04-16 start class for led matrix
2021-04-17 Basic configuration of Led Matrix
2021-04-17 Added support files for Led Matrix
2021-04-26 deleted DAC_Driver thread
2021-04-27 Buffer implementation for Led Matrix
2021-04-27 Optimizations on buffer and leds behaviour
2021-04-28 added ADC sampling
2021-04-29 Writable strings on Led Matrix
2021-05-02 Led Matrix Optimizations
2021-05-03 controls printed on matrix + adc filter
2021-05-03 moved ADC filter to another file
2021-05-07 Implemented Interrupt Routine for Led Matrix
2021-05-07 Fixed Interrupt disable and removed thread
    [LedMatrix_Driver.cpp]
2021-05-07 fixed random problem on restart + deleted old thread variables
    [LedMatrix_Driver.cpp, LedMatrix_Driver.h]
2021-05-10 added button to switch effects/sources
2021-05-11 fixed mutex crash + pot loop changes
    [AudioChain.cpp, DAC_Driver.cpp]
2021-08-30 bug fixes + optimizations + added FIlter
    [AudioChain.cpp, LedMatrix_Driver.cpp]
2021-09-03 fixed ADC audio problem
    [ADC_Driver.cpp, AudioChain.cpp]
